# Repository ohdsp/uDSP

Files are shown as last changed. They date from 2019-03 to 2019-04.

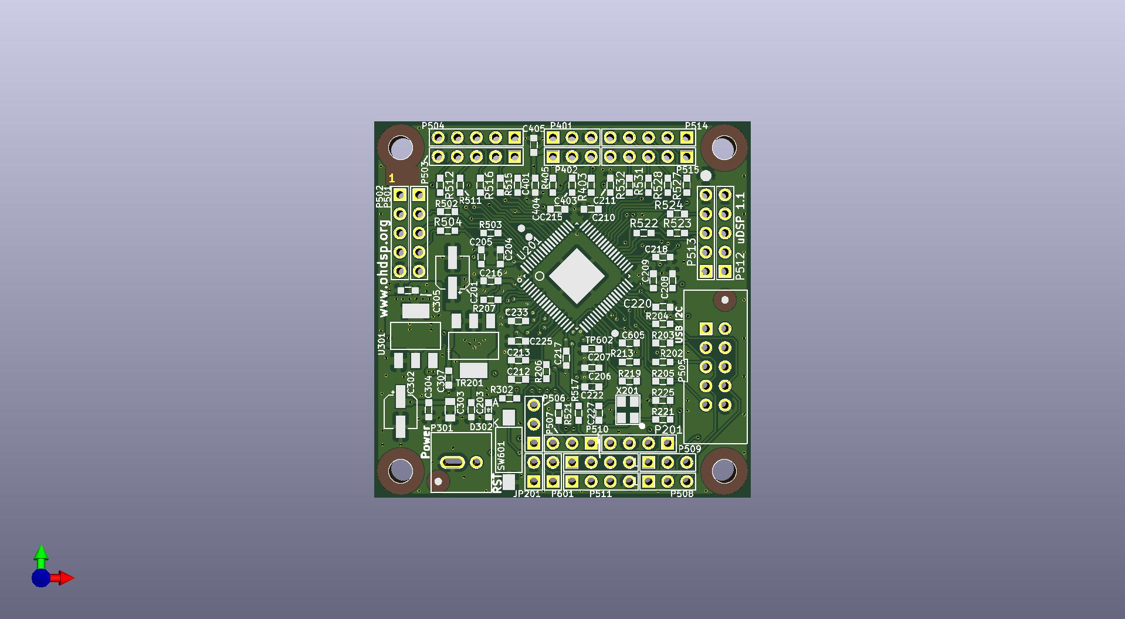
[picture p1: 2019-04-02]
JPEGs/Front.jpg

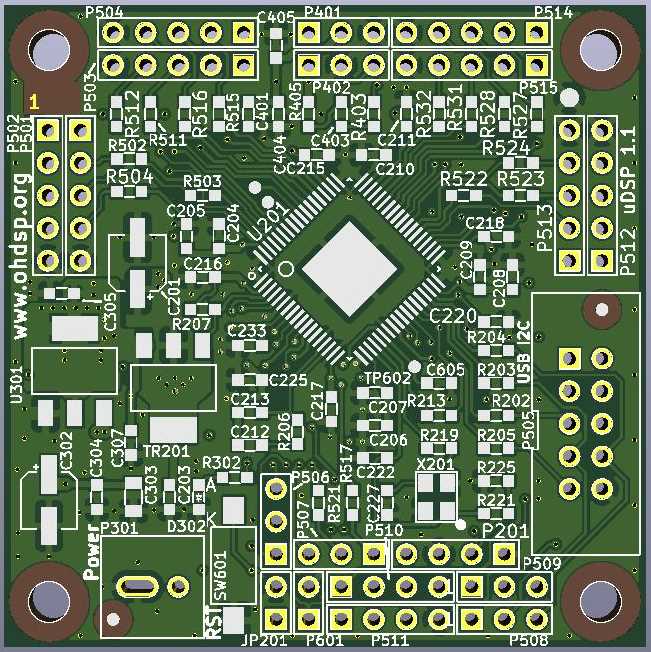
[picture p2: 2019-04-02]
JPEGs/Front - small.jpg

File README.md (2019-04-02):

# [Open Hardware DSP Platform](www.ohdsp.org)
## uDSP 1.1
### A 5cm x 5cm DSP board using Analog Device SigmaDSP devices
### Supports ADAU1466, ADAU1462, ADAU1452, ADAU1451, ADAU1450
### Selfboot and external control supported
### All I/O routed out
---
# README
### Disclaimer
Copyright Paul Janicki 2019

Licensed under the TAPR Open Hardware License (www.tapr.org/OHL)

This documentation is distributed WITHOUT ANY EXPRESS OR IMPLIED WARRANTY, INCLUDING OF MERCHANTABILITY, SATISFACTORY QUALITY AND FITNESS FOR A PARTICULAR PURPOSE.

### Changelog
1.1:
Add CS1 and CS2 to SPI header - removed 3V3 power
Add 3V3 monitor option to reset circuit

### What is this repository for?

**Quick summary**

This is a simple self-bootable DSP board with 4 I2S input and 4 I2S output connectors. When used with the ADAU146x, ADAU1451 and ADAU1452 parts there are also optical input and output connectors for off-board mounted connectors. 

There is an SPI connector for connection to the Analog Devices SigmaStudio USBi to EZ-Board Adapter (ADZS-USBI2EZB) or equivalent. 

The board also features master and slave SPI connectors for use with other boards. 

The board has space for a self-boot EEPROM. When used with the ADZS-USBI2EZB or compatible device the board can be programmed to selfboot with the last program written. The board can also be controlled using an external mircocontroller.

This board forms part the of the open hardware DSP platform which is designed to be a highly customisable and flexible DSP platform. 

This repository contains the KiCad design files, manufacturing Gerber/drill files, and PDF/drawing files for this board.

### What is the project folder structure?
Most folder names are self explanatory. Starting from the top level:
*uDSP*
+ *Bill of Materials*  - This contains the bill of materials in CVS, LibreOffice Calc and XML formats
+ *Drawings* - This contains PDF and SVG Schematic and PCB files
+ *Gerbers* - This contains the PCB Gerbers and drill drawings for manufacture, there is also a zip file ready to send to most manufacturers
+ *KiCad* - This contains the original KiCad schematic and PCB design files

### How do I get set up?

**Summary of set up**

1. Set your self up a directory on a local disk, something simple will make life easier (eg C:\Electronics on Windows as used here), but anywhere will do just fine.
2. Download the Kicad-Libs from [https://github.com/ohdsp/KiCad-Libs](https://github.com/ohdsp/KiCad-Libs) and place in C:\Electronics\Kicad-Libs (or your chosen folder) 
3. Create a OHDSP subdirectory in C:\Electronics (so C:\Electronics\OHDSP)
3. Download this project to C:\Electronics\OHDSP\uDSP
4. Fire up Kicad
5. Open the main project file C:\Electronics\OHDSP\uDSP\KiCad\uDSP.pro
7. Do as you wish with the project, just keep it under the TAPR Open Hardware License.
Note: For library issues see below.

Make sure your git setup doesn't exclude files used in the project (like .LIB files) or things may go wrong down the line.

**KiCad Library Configuration**

Note that libraries are setup using relative paths, if you follow the above instructions things should work just fine. Below is the default library setup.

To setup eeschema component libraries:
From KiCad main window go to menu Tools -> Edit Schematic Symbols. In the new Window go to menu Preferences -> Manage Symbol Libraries.

On the new "Symbol Libraries" window select the "Project Specific Libraries" tab. The "Append Library" and "Remove Library" buttons can be used to add/remove enteries.
The standard setup is:

| | Active | Nickname | Library Path | Plugin Type | Options | Description |
|---|---|---|---|---|---|---|
| 1 | Ticked | power | ${KICAD_SYMBOL_DIR}/power.lib | Legacy | (blank) | (blank) |
| 2 | Ticked | MyKiCadLibs-Lib | ${KIPRJMOD}/../../../KiCad-Libs/MyKiCadLibs-Lib.lib | Legacy | (blank) | (blank) |

${KICAD_SYMBOL_DIR}  is set under the Enviromnet Variable Configuration. Close Symbol Libraries dialogue and go "Preferences" -> "Configure Paths..."

${KICAD_SYMBOL_DIR} is set to C:\Program Files\KiCad\share\kicad\library - this is the default for a KiCad install on the C drive

${KIPRJMOD} is automatically set to the location of the project (.pro file), in this example this would be C:\Electronics\OHDSP\uDSP\KiCad

To setup Pcbnew libraries:
From KiCad main window go to menu Tools -> Edit PCB Footprints. In the new Window go to menu Preferences -> Manage Symbol Libraries.

On the new "Symbol Libraries" window select the "Project Specific Libraries" tab. The "Append Library" and "Remove Library" buttons can be used to add/remove enteries.
The standard setup is:

| | Active | Nickname | Library Path | Plugin Type | Options | Description |
|---|---|---|---|---|---|---|
| 1 | Ticked | MyKiCadLibs-Footprints | ${KIPRJMOD}/../../../KiCad-Libs/MyKiCadLibs-Footprints.pretty | KiCad | (blank) | (blank) |

${KIPRJMOD} is automatically set to the location of the project (.pro file), in this example this would be C:\Electronics\OHDSP\uDSP\KiCad

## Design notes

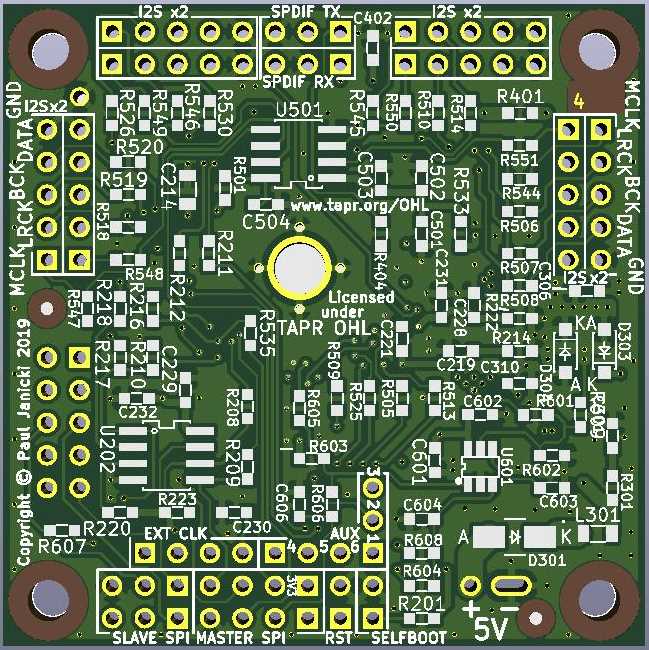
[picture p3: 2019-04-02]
JPEGs/Bottom - small.jpg

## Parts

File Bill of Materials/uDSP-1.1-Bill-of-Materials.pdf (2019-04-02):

ADC-PCM4202-SE-Bill-of-Materials-1.1

Licensed under the TAPR Open Hardware License (www.tapr.org/OHL)

### uDSP-1.1 Bill of Materials 02 April 2019

Reference | Quantity | Footprint | Value | Description | Type | Voltage | Size | Tolerance | Power | Current
C201 | 1 CAP-SMD-SIZE-B | | 22u | 'Low impedance aluminium electrolytic capacitor - Panasonic FP, FK or Similar | 'Case B SMD Aluminium Electrolytic | '6V3 | ' | ' | ' | '
C203 C204 C206 C208 C210 C215 C216 C217 C218 C225 C229 C230 C233 C304 C305 C307 C404 C405 C503 C602 C605 C606 | 22 SMD-0603 | | 100n | 'Ceramic capacitor | 'X7R | '50V | '0603 | '10% | ' | '
C205 C207 C209 C211 C220 C403 C603 C604 | 8 SMD-0603 | | 10n | 'Ceramic capacitor | 'X7R | '50V | '0603 | '10% | ' | '
C212 | 1 SMD-0603 | | 5n6 | 'Ceramic capacitor | 'X7R | '50V | '0603 | '10% | ' | '
C213 | 1 SMD-0603 | | 150p | 'Ceramic capacitor | 'C0G | '50V | '0603 | '5% | ' | '
C214 | 1 SMD-0805 | | 10u | 'Ceramic capacitor | 'X5R | '10V | '0805 | '20% | ' | '
C219 C228 C301 C401 C501 | 5 SMD-0603 | | 100p | 'Ceramic capacitor | 'NP0 | '50V | '0603 | '5% | ' | '
C221 C231 C232 | 3 SMD-0603 | | 10u | 'Ceramic capacitor | 'X5R | '10V | '0603 | '10% | ' | '
C222 C227 | 2 SMD-0603 | | 33p | 'Ceramic capacitor | 'C0G | '25V | '0603 | '5% | ' | '
C302 | 1 CAP-SMD-SIZE-B | | 10u | 'Low impedance aluminium electrolytic capacitor - Panasonic FP, FK or Similar | 'Case B SMD Aluminium Electrolytic | '10V | ' | ' | ' | '
C303 | 1 SMD-0805 | | 22u | 'Ceramic capacitor | 'X5R | '25V | '0805 | '20% | ' | '
C306 | 1 SMD-0603 | | 22u | 'Ceramic capacitor | 'X5R | '10V | '0603 | '20% | ' | '
C310 C601 | 2 SMD-0603 | | 10u | 'Ceramic capacitor | 'X5R | '10V | '0603 | '20% | ' | '
C402 C502 | 2 SMD-0603 | | 22u | 'Ceramic capacitor | 'X5R | '10V | '0603 | '10% | ' | '
C504 | 1 SMD-0603 | | 1n | 'Ceramic capacitor | 'X7R | '50V | '0603 | '10% | ' | '
D301 | 1 DIODE-SMA | | B240A | 'B240A 2A 40V Schottky Rectifier - SMA (DO-214AC) | ' | ' | ' | ' | ' | '
D302 | 1 SMD-0603-LED | | LED 0603 | 'LED - SMD - Vf 1.8V to 2.2V | ' | ' | '0603 | ' | ' | '
D303 D304 | 2 DIODE-SOD-123 | | 1N5819HW | '1A 40V Schottky Rectifier - SOD-123 | ' | ' | ' | ' | ' | '
JP201 P601 | 2 CONN_SIL_2_1MM | | CONN_2x1 | '1x2 2.54mm pitch pin header | ' | ' | ' | ' | ' | '
L301 | 1 SMD-0805 | | 600R@100MHz | 'Ferrite bead, current rating 1A or higher, 600R@100MHz | ' | ' | '0805 | ' | ' | '=>2A
P201 P510 P511 | 3 CONN_SIL_4_1MM | | CONN_4x1 | '1x4 2.54mm pitch pin header | ' | ' | ' | ' | ' | '
P301 | 1 CONN-2WAY-2.54mm-3.81mm-SPACING | | CONN_2x1 | '2 way screw terminal, any 2.54mm to 3.81mm pitch part | ' | ' | ' | ' | ' | '
P401 P402 P506 P507 P508 P509 | 6 CONN_SIL_3_1MM | | CONN_3x1 | '1x3 2.54mm pitch pin header | ' | ' | ' | ' | ' | '
P505 | 1 CONN_DIL_2X5_BOX_1MM | | CONN_02X05 | '2x5 2.54mm pitch box header | ' | ' | ' | ' | ' | '
P501 P502 P503 P504 P512 P513 P514 P515 | 8 CONN_SIL_5_1MM | | CONN_5x1 | '1x5 2.54mm pitch pin header | ' | ' | ' | ' | ' | '
R202 R208 R209 R210 R211 R212 R213 R216 R403 R404 R518 R519 R520 R522 R523 R524 R526 R527 R528 R530 R531 R532 R544 R545 R546 R547 R548 R549 R550 R551 | 30 SMD-0603 | | 22 | 'Thick or thin film resistor | ' | ' | '0603 | '1% | '63mW | '
R203 R204 R205 R502 R503 R504 R506 R507 R508 R510 R511 R512 R514 R515 R516 R535 R607 | 17 SMD-0603 | | 0 | 'Thick or thin film resistor | ' | ' | '0603 | '1% | '63mW | '
R206 | 1 SMD-0603 | | 4k3 | 'Thick or thin film resistor | ' | ' | '0603 | '1% | '63mW | '
R201 R207 R501 | 3 SMD-0603 | | 1K | 'Thick or thin film resistor | ' | ' | '0603 | '1% | '63mW | '
R214 R222 R401 R533 | 4 SMD-0603 | | 1 | 'Thick or thin film resistor | ' | ' | '0603 | '1% | '63mW | '
R217 R220 R223 R405 R602 | 5 SMD-0603 | | 10K | 'Thick or thin film resistor | ' | ' | '0603 | '1% | '63mW | '
R219 R604 R605 R606 | 4 SMD-0603 | | 100 | 'Thick or thin film resistor | ' | ' | '0603 | '1% | '63mW | '
R218 R221 R225 R609 | 4 SMD-0603 | | N/F | 'Thick or thin film resistor | ' | ' | '0603 | '1% | '63mW | '
R301 | 1 SMD-0603 | | 47 | 'Thick or thin film resistor | ' | ' | '0603 | '1% | '63mW | '
R302 | 1 SMD-0603 | | 470 | 'Thick or thin film resistor | ' | ' | '0603 | '1% | '63mW | '
R505 R509 R513 R517 R521 R525 | 6 SMD-0603 | | 4K7 | 'Thick or thin film resistor | ' | ' | '0603 | '1% | '63mW | '
R601 | 1 SMD-0603 | | 18K7 | 'Thick or thin film resistor | ' | ' | '0603 | '1% | '63mW | '
R603 R608 | 2 SMD-0603 | | 2K2 | 'Thick or thin film resistor | ' | ' | '0603 | '1% | '63mW | '
SW601 | 1 SW_TACT_SMD_FSMSM | | FSMSM | '3.5mm x 6mm SMD tactile switch - e.g. Alcoswitch FSMSM | ' | ' | ' | ' | ' | '
TR201 | 1 IC-SOT-223 | | NJT4030PT3G | 'On Semi NJT4030PT3G PNP Transistor (min 2W, 200hFE, 2A) | ' | ' | ' | ' | ' | '
U201 | 1 IC-LFCSP72-HANDFIT | | ADAU1452WBCPZ | 'SigmaDSP Digital Audio Processor - Use ADAU1462, ADAU1466, ADAU1452, ADAU1451, or ADAU1450 | ' | ' | ' | ' | ' | '
U202 | 1 IC_SOIC_8 | | M95M01-RMN6TP | '1 Mbit SPI Bus Serial EEPROM - 8 pin SOIC | ' | ' | ' | ' | ' | '
U301 | 1 IC-SOT-223 | | TLV1117LV33DCY | 'TLV1117LV 1-A, Positive Fixed-Voltage, Low-Dropout Regulator - Fixed 3V3 | ' | ' | ' | ' | ' | '
U501 | 1 IC_SOIC_8 | | NB3L553 | 'On Semi - 1:4 Clock Fanout Buffer | ' | ' | ' | ' | ' | '
U601 | 1 IC-SOT23-6 | | NCP308SNADJT1G | 'On Semi NCP308SNADJT1G SOT-23-6 TSOP-6 Supervisor | ' | ' | ' | ' | ' | '
X201 | 1 XTAL_3.2x2.5_4PIN | | 24M576 | 'Crystal 3.2mm x 2.5mm - eg Abracon ASE-24.576MHZ-LC-T | ' | ' | ' | ' | ' | '

### Open Hardware DSP Platform – www.ohdsp.org

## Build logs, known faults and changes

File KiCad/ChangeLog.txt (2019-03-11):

Schematic changelog revision 2.0:
Changes jumpers from CN to JP designators (JP201,JP401)
Change various 22uF to 10uF
Removed R from all resistors values
Change R234,R235 from 68ohm to 75ohm
Replace NB3L553 supply inductors L501/L502 with resistors R584/R585 (still 0805 parts)
General tidy up of schematics, part numbers, text etc.
Change P304 from 5mm/5.08mm to smaller connector (same as other boards)
Change D301,D302 to B240A
Change D303,D305,D306,D307,D501-D512 to SS14
Update connectors with 1mm holes
Change PVDD filter resistor to inductor (L202)
Change L302 to TYS50404R7N-10
Change mounting holes and added fiducials
Delete C259, C262, C255, C330,C332
Change U302 to lower cost TLV1117LV33DCY fixed output regulator
Added new SPI slave and master connector P511/P512
Moved/added R227, R236, R248, R586 and R587
Change C216 to 10uF
Removed C202-C204
Updated all parts with extra details/fields
Change clock buffer pin orders

PCB changelog revision 2.0:
Added Master and Slave SPI connectors P511 and P512
Moved EEPROM/SPI/I2C connectors
Changed L501/L502 to R584/R585
Silkscreen changes
Renamed jumpers from CN to JP designators
Fixed disconnected ground stitching vias
Change D301 from SMB to SMA footprint
Update all 2x5 header footprints with key
Update all headers with 1mm holes
Change PVDD 1R resistor to inductor (L202)
Chage L302 to TYS50404R7N-10
Change mounting holes
Delete C259, C262, C255, C330,C332
Update ADP2301 footprint with pin 1 indicator
Change U302 to 1117 regulator
Update design rules
Added fiducials
Change U302 to SOT223
Moved/added R227, R236, R248, R586 and R587
Moved reset switch, crystals and associatedparts
Increase part spacing around U202
Removed C202-C204
Moved U502, U203, and surrounding parts
Adjusted capacitor spacing around ADAU1452/U201
Change clock buffer pin orders/relayout buffers

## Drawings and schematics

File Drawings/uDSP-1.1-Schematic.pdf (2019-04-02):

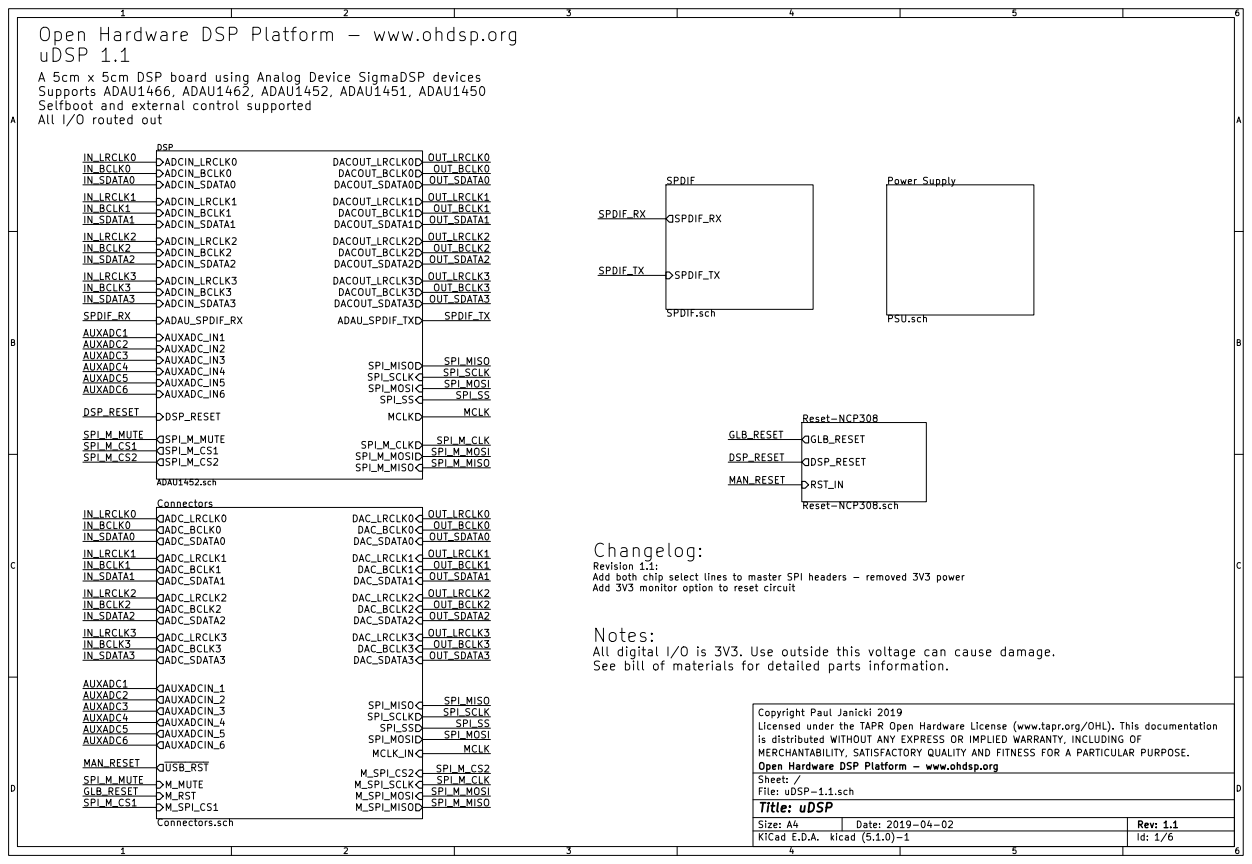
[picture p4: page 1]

Open Hardware DSP Platform - www.ohdsp.org
uDSP 1.1
A 5cm x 5cm DSP board using Analog Device SigmaDSP devices
Supports ADAU1466, ADAU1462, ADAU1452, ADAU1451, ADAU1450
Selfboot and external control supported
All I/O routed out

IN_BCLK0
IN_SDATA0 | OUT_SDATA0

IN_BCLK1 | OUT_BCLK1
IN_SDATA1 | OUT_SDATA1

IN_BCLK2 | OUT_BCLK2
IN_SDATA2 | OUT_SDATA2

IN_BCLK3 | OUT_BCLK3
IN_SDATA3 | OUT_SDATA3

GLB_RESET RST_IN

SPI_M_MOSI
SPI_M_MISO

IN_SDATA0

Changelog: Revision 1.1: Add both chip select lines to master SPI headers - removed 3V3 power

IN_BCLK1

OUT_LRCLK1

Add 3V3 monitor option to reset circuit

IN_BCLK2
IN_SDATA2

Notes:
All digital I/O is 3V3. Use outside this voltage can cause damage.
See bill of materials for detailed parts information.

IN_BCLK3
IN_SDATA3

AUXADCIN_1 AUXADCIN_2 AUXADCIN_3 AUXADCIN_4 AUXADCIN_5 AUXADCIN_6

Copyright Paul Janicki 2019
Licensed under the TAPR Open Hardware License (www.tapr.org/OHL). This documentation
is distributed WITHOUT ANY EXPRESS OR IMPLIED WARRANTY, INCLUDING OF
MERCHANTABILITY, SATISFACTORY QUALITY AND FITNESS FOR A PARTICULAR PURPOSE.
File: uDSP-1.1.sch Sheet: / Open Hardware DSP Platform - www.ohdsp.org

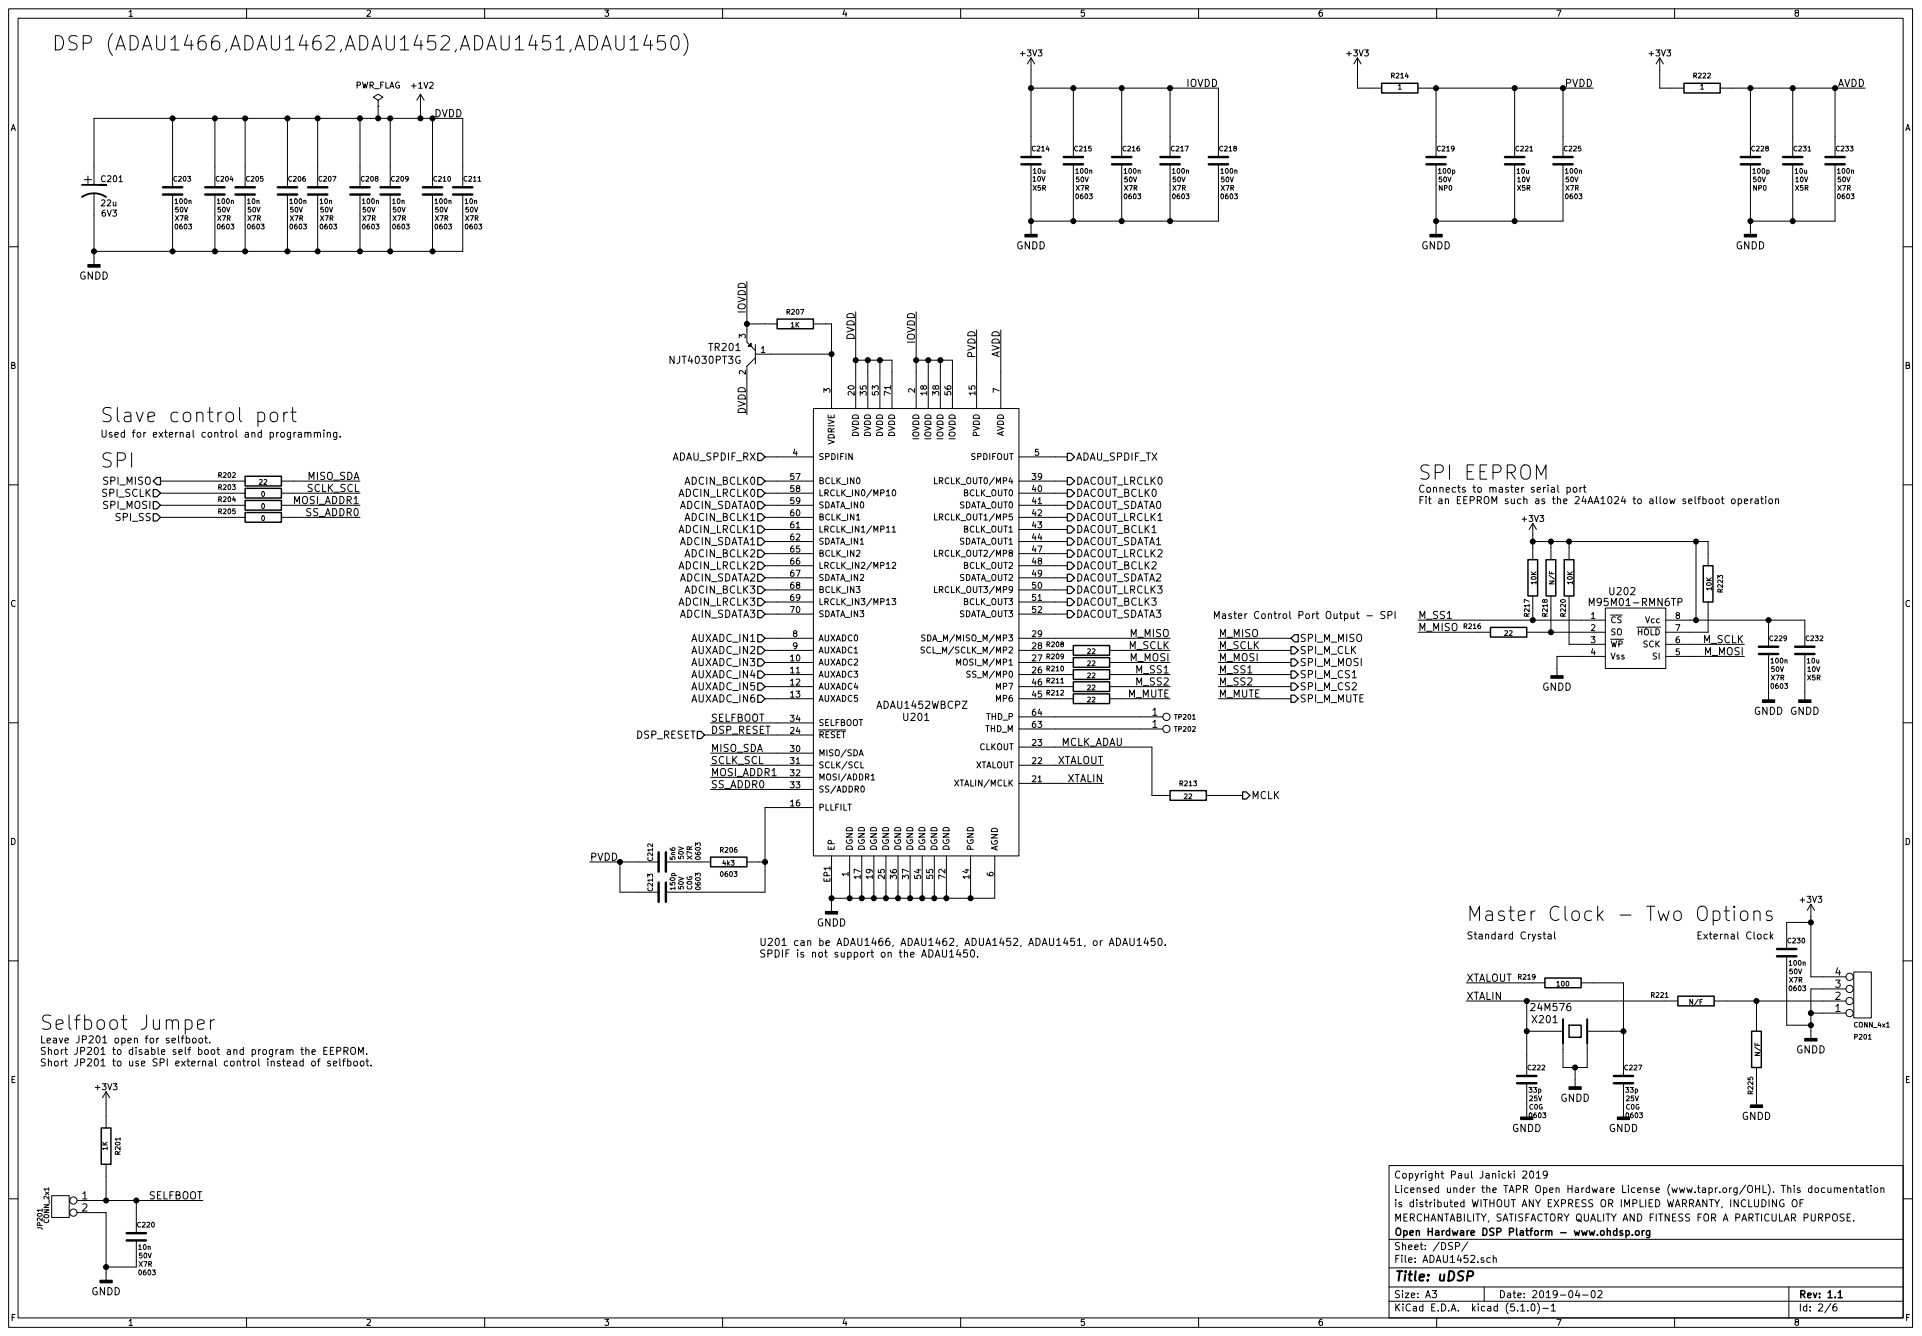
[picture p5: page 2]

1 AUXADC2 10 AUXADC3 11 AUXADC4 12 AUXADC5 13 PGND 14 PVDD 15 PLLFILT 16 DGND 17 IOVDD 18 DGND 19 IOVDD

2 DVDD 20 XTALIN/MCLK 21 XTALOUT 22 CLKOUT 23 RESET 24 DGND 25 SS_M/MP0 26 MOSI_M/MP1 27 SCL_M/SCLK_M/MP2 28 SDA_M/MISO_M/MP3 29 VDRIVE

3 MISO/SDA 30 SCLK/SCL 31 MOSI/ADDR1 32 SS/ADDR0 33 SELFBOOT 34 DVDD 35 DGND 36 DGND 37 IOVDD 38 LRCLK_OUT0/MP4 39 SPDIFIN 4 BCLK_OUT0 40 SDATA_OUT0 41

Used for external control and programming.

SPI EEPROM
Connects to master serial port
Fit an EEPROM such as the 24AA1024 to allow selfboot operation

Master Clock - Two Options

SPDIF is not support on the ADAU1450.

Leave JP201 open for selfboot.

Copyright Paul Janicki 2019
Licensed under the TAPR Open Hardware License (www.tapr.org/OHL). This documentation
is distributed WITHOUT ANY EXPRESS OR IMPLIED WARRANTY, INCLUDING OF
MERCHANTABILITY, SATISFACTORY QUALITY AND FITNESS FOR A PARTICULAR PURPOSE.
File: ADAU1452.sch Sheet: /DSP/ Open Hardware DSP Platform - www.ohdsp.org

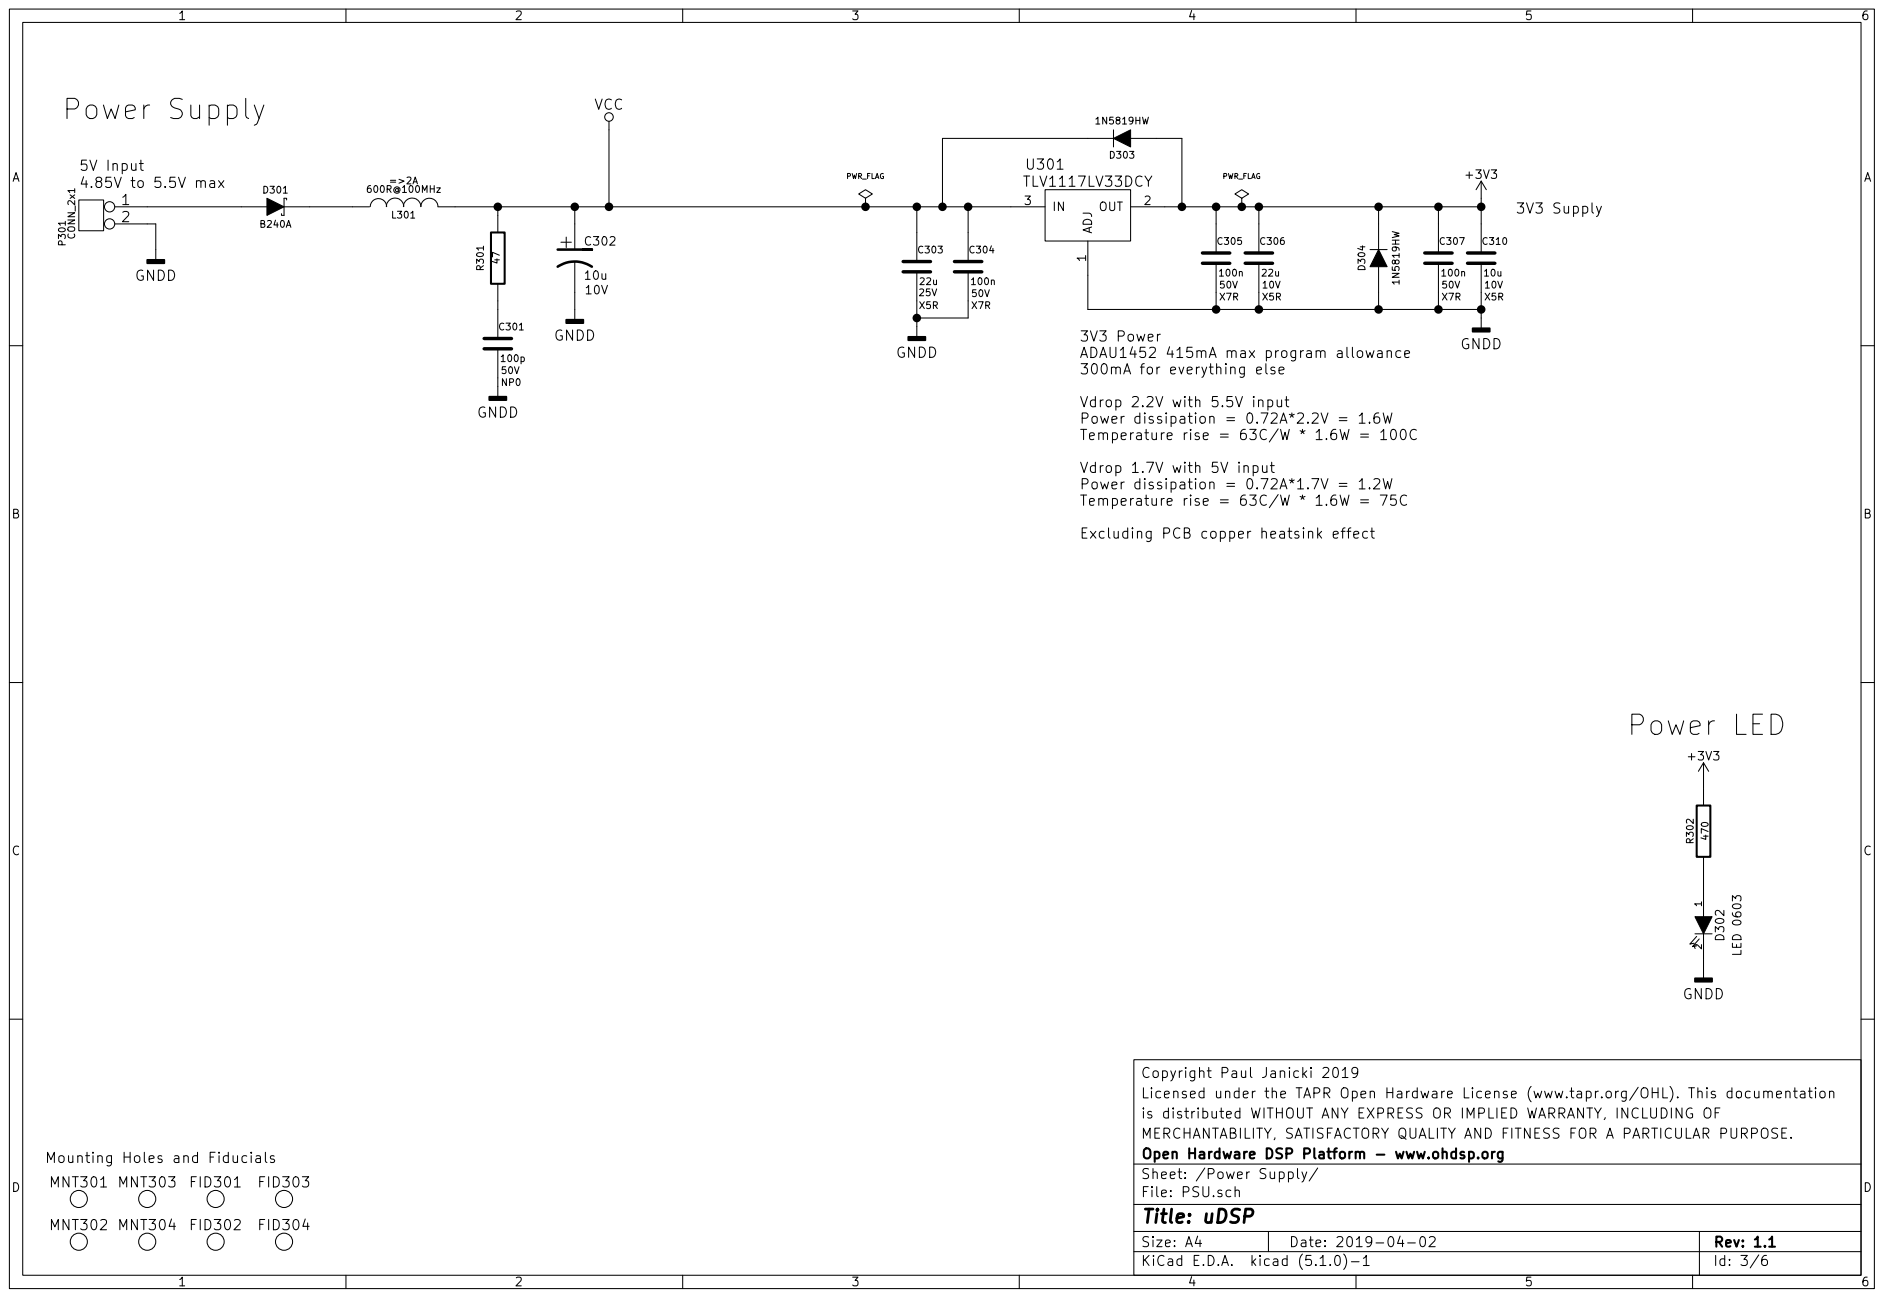
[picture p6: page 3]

5V Input
Excluding PCB copper heatsink effect 4.85V to 5.5V max

+3V3 3V3 Power ADAU1452 415mA max program allowance

Copyright Paul Janicki 2019
Licensed under the TAPR Open Hardware License (www.tapr.org/OHL). This documentation
is distributed WITHOUT ANY EXPRESS OR IMPLIED WARRANTY, INCLUDING OF
MERCHANTABILITY, SATISFACTORY QUALITY AND FITNESS FOR A PARTICULAR PURPOSE.
Open Hardware DSP Platform - www.ohdsp.org
File: PSU.sch Sheet: /Power Supply/
Id: 3/6 Title: uDSP

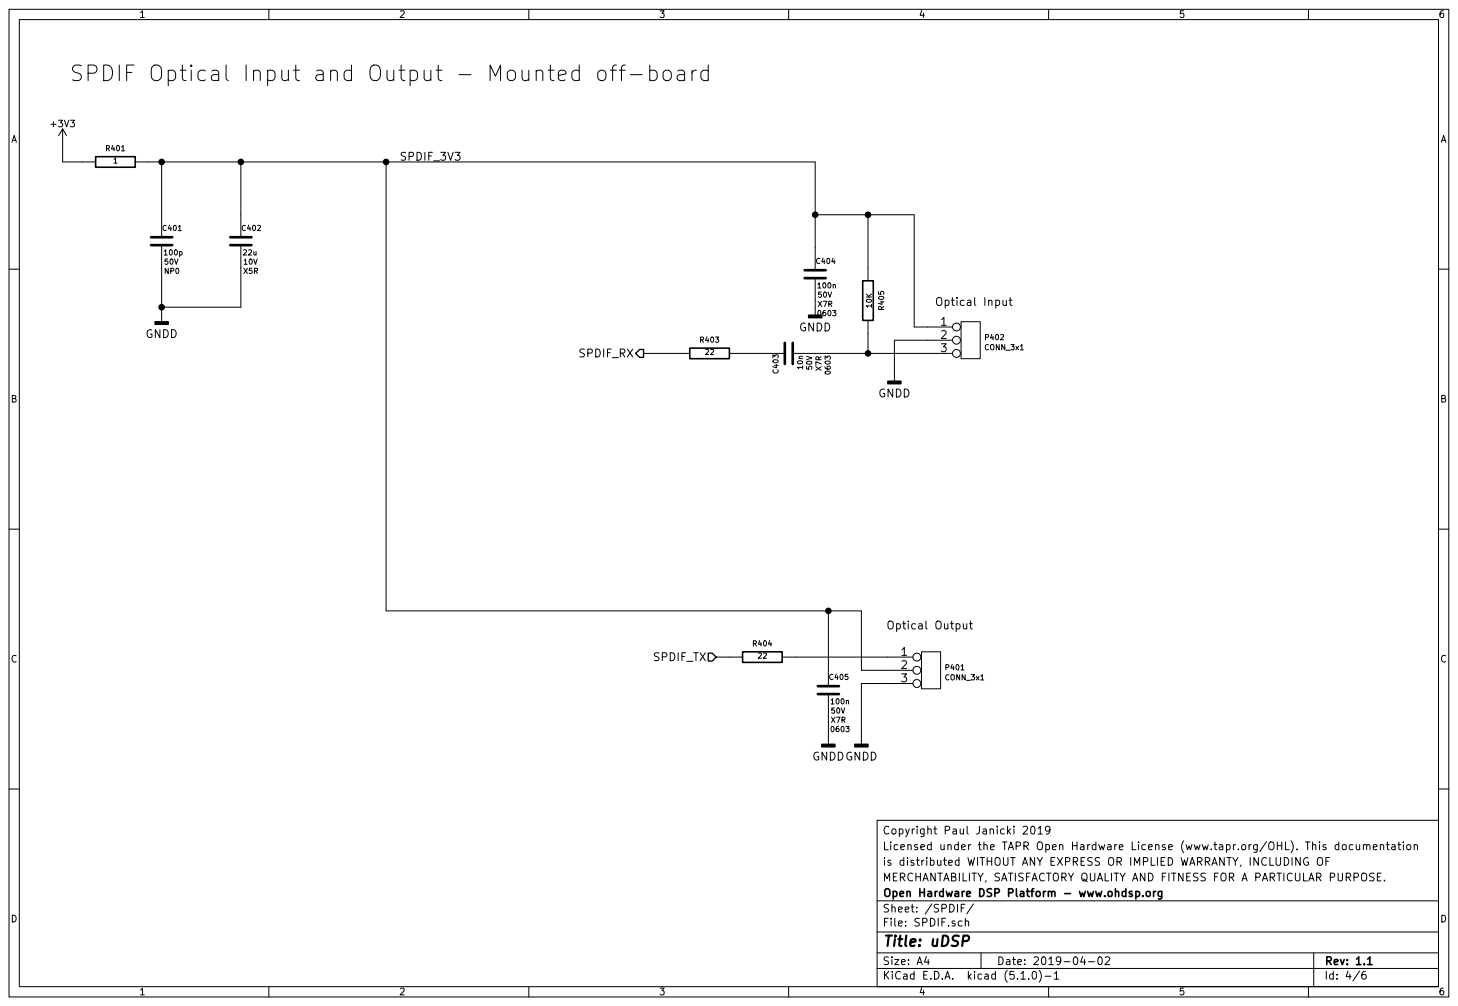
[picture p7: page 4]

SPDIF Optical Input and Output - Mounted off-board

Copyright Paul Janicki 2019
Licensed under the TAPR Open Hardware License (www.tapr.org/OHL). This documentation
is distributed WITHOUT ANY EXPRESS OR IMPLIED WARRANTY, INCLUDING OF
MERCHANTABILITY, SATISFACTORY QUALITY AND FITNESS FOR A PARTICULAR PURPOSE.
File: SPDIF.sch Sheet: /SPDIF/ Open Hardware DSP Platform - www.ohdsp.org

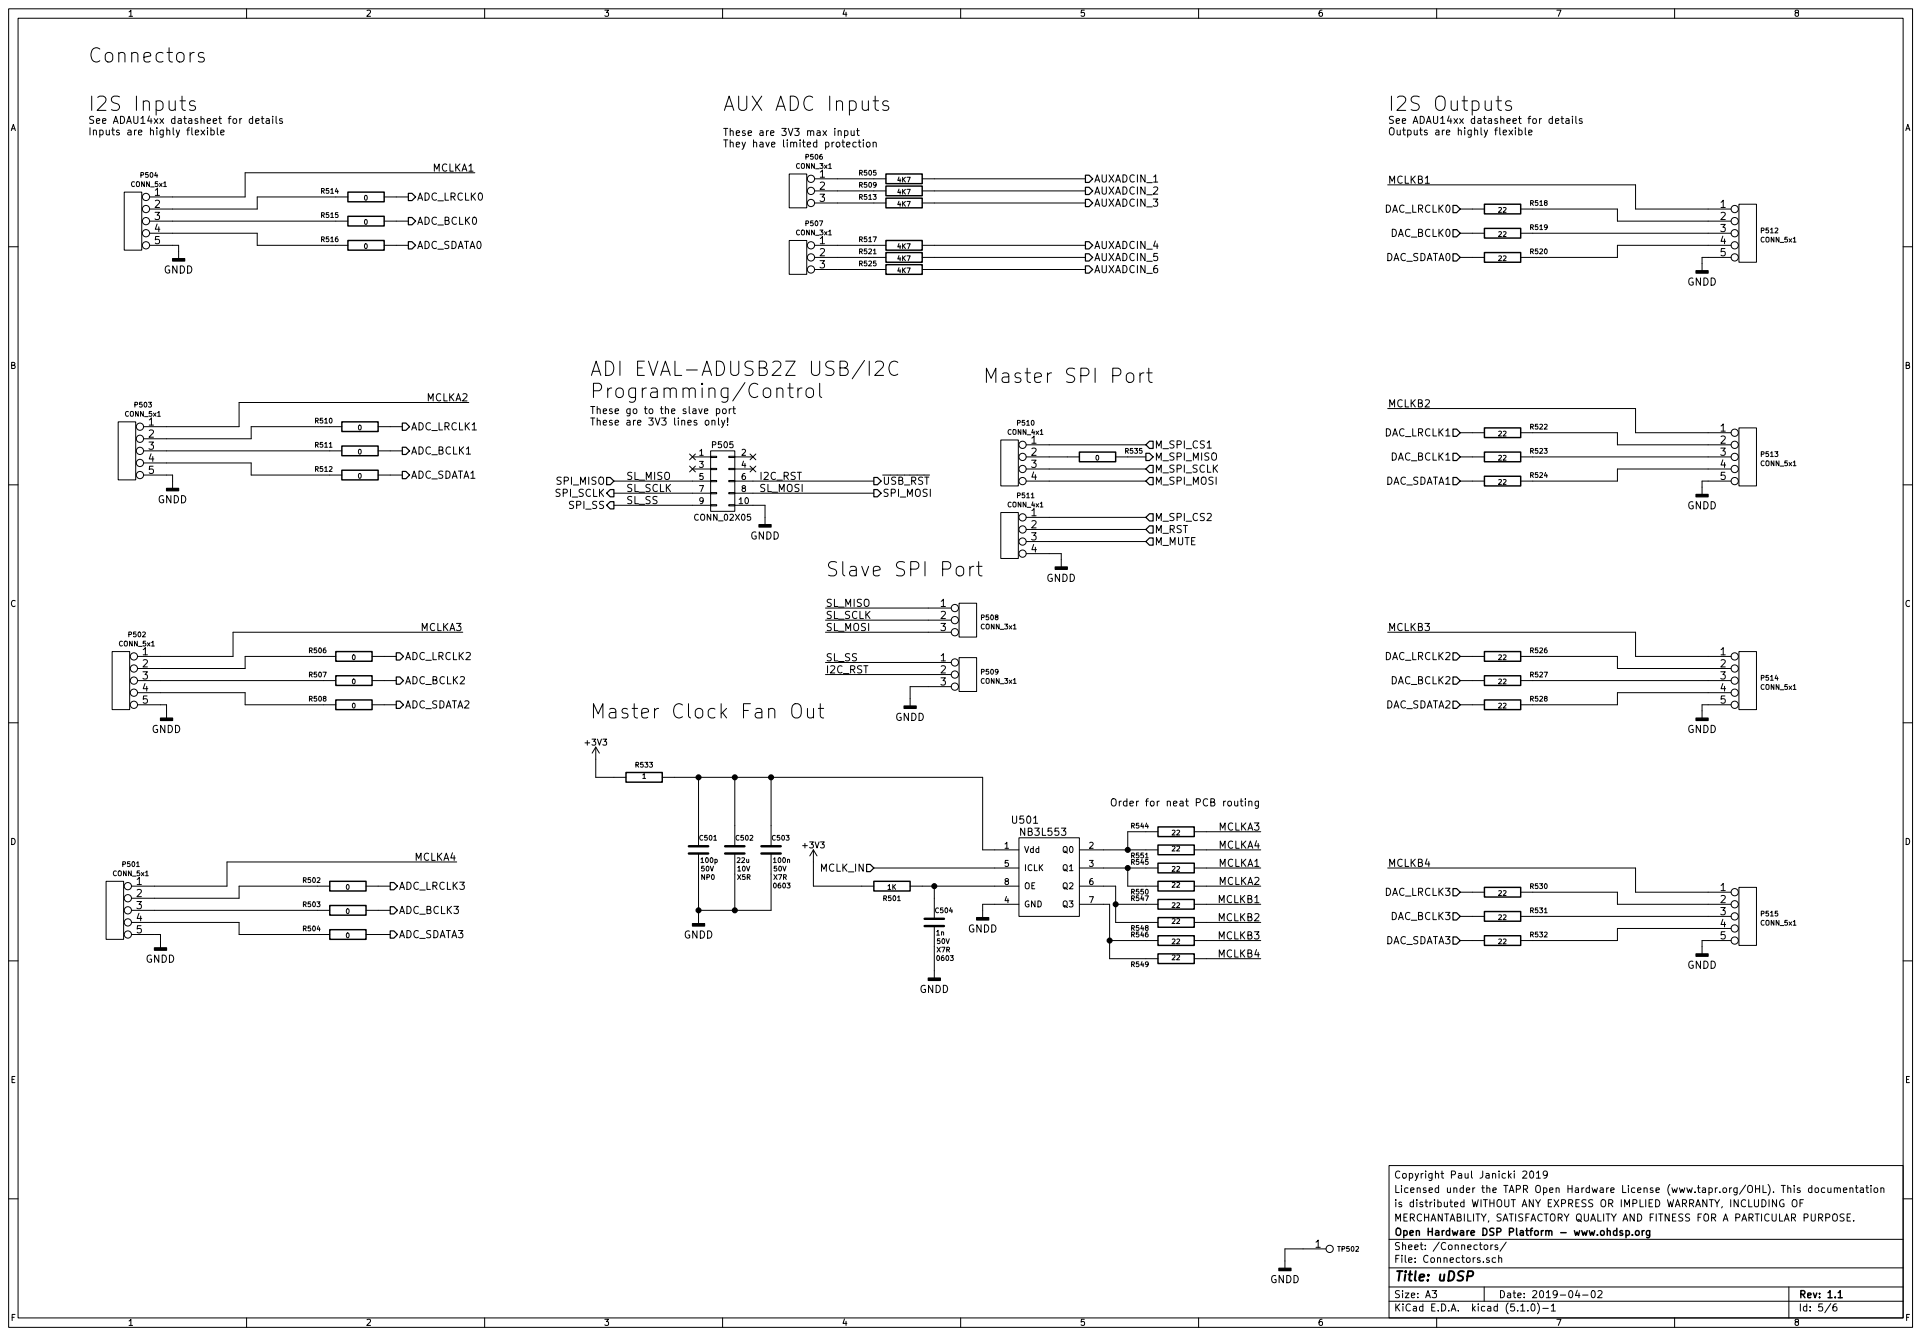
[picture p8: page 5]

I2S Outputs
See ADAU14xx datasheet for details Outputs are highly flexible

These are 3V3 max input
They have limited protection

These go to the slave port

These are 3V3 lines only! ADC_LRCLK1

Master Clock Fan Out

Order for neat PCB routing

Copyright Paul Janicki 2019
Licensed under the TAPR Open Hardware License (www.tapr.org/OHL). This documentation
is distributed WITHOUT ANY EXPRESS OR IMPLIED WARRANTY, INCLUDING OF
MERCHANTABILITY, SATISFACTORY QUALITY AND FITNESS FOR A PARTICULAR PURPOSE.
File: Connectors.sch Sheet: /Connectors/ Open Hardware DSP Platform - www.ohdsp.org

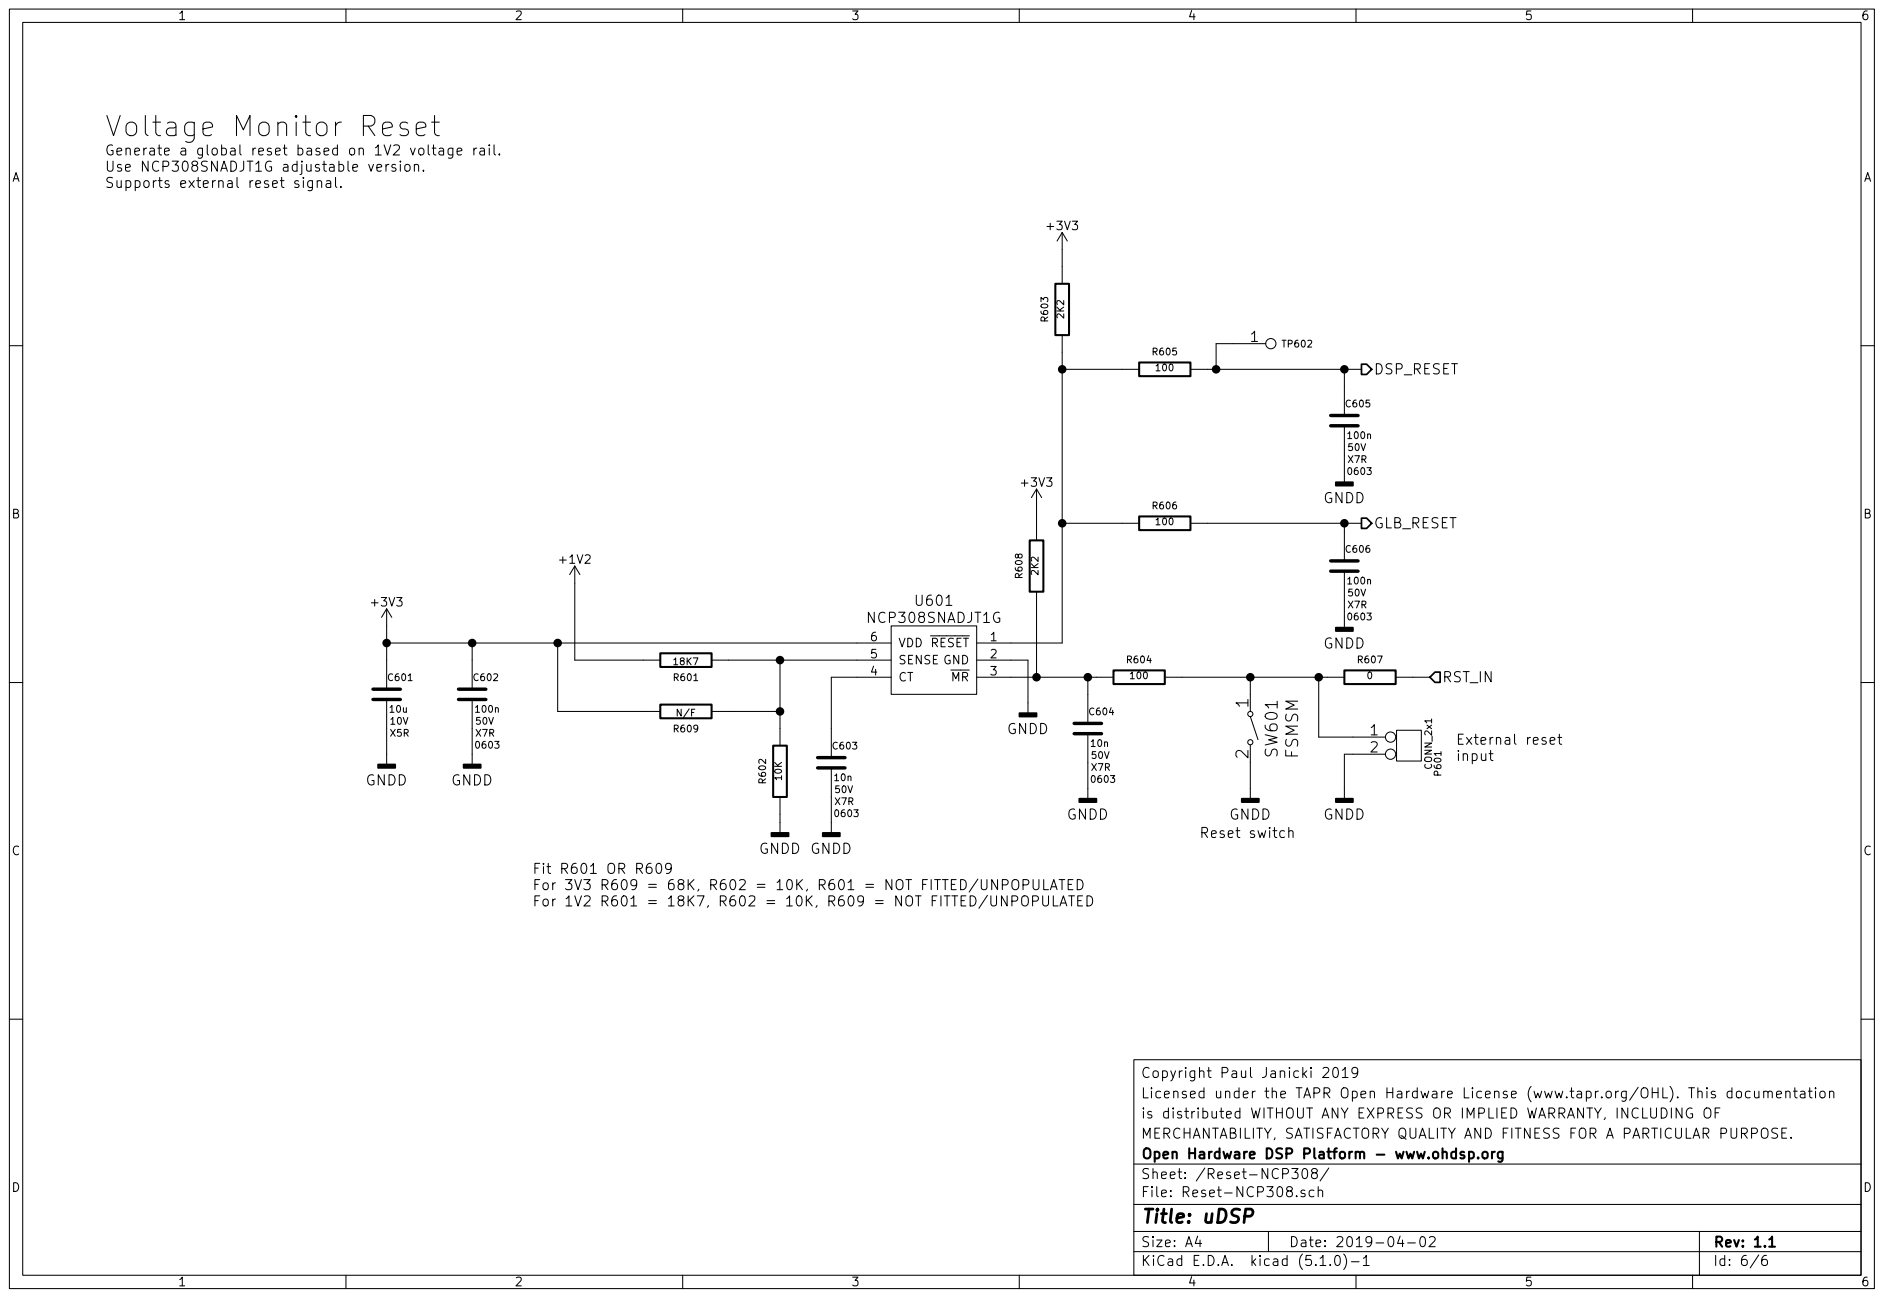
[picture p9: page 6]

Generate a global reset based on 1V2 voltage rail.
Use NCP308SNADJT1G adjustable version.
Supports external reset signal.

For 1V2 R601 = 18K7, R602 = 10K, R609 = NOT FITTED/UNPOPULATED

Copyright Paul Janicki 2019
Licensed under the TAPR Open Hardware License (www.tapr.org/OHL). This documentation
is distributed WITHOUT ANY EXPRESS OR IMPLIED WARRANTY, INCLUDING OF
MERCHANTABILITY, SATISFACTORY QUALITY AND FITNESS FOR A PARTICULAR PURPOSE.
File: Reset-NCP308.sch Sheet: /Reset-NCP308/ Open Hardware DSP Platform - www.ohdsp.org

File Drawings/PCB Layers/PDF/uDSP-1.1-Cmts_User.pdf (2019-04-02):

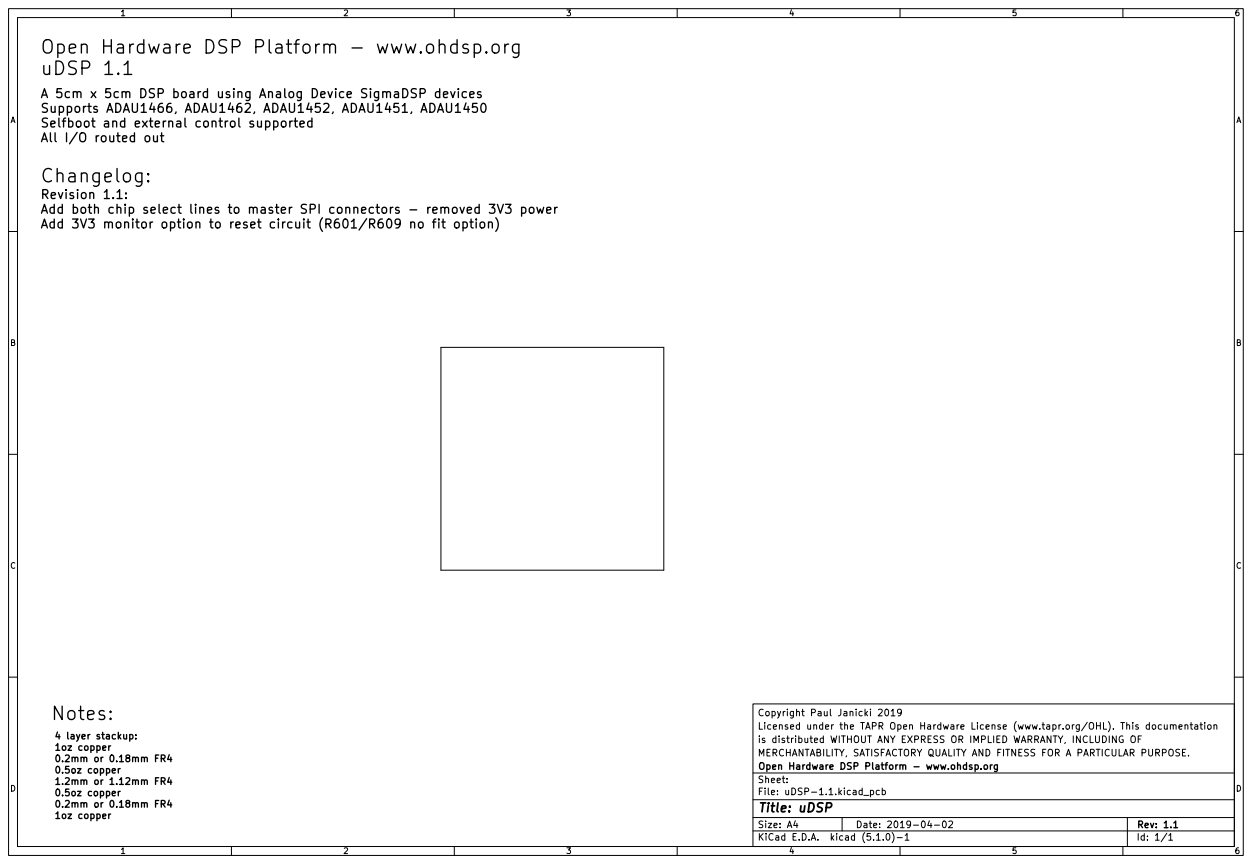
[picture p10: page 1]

Open Hardware DSP Platform - www.ohdsp.org
uDSP 1.1

A 5cm x 5cm DSP board using Analog Device SigmaDSP devices
Supports ADAU1466, ADAU1462, ADAU1452, ADAU1451, ADAU1450
Selfboot and external control supported
All I/O routed out
Changelog:
Revision 1.1:
Add both chip select lines to master SPI connectors - removed 3V3 power
Add 3V3 monitor option to reset circuit (R601/R609 no fit option)

Copyright Paul Janicki 2019
Licensed under the TAPR Open Hardware License (www.tapr.org/OHL). This documentation
is distributed WITHOUT ANY EXPRESS OR IMPLIED WARRANTY, INCLUDING OF
MERCHANTABILITY, SATISFACTORY QUALITY AND FITNESS FOR A PARTICULAR PURPOSE.
File: uDSP-1.1.kicad_pcb Sheet: Open Hardware DSP Platform - www.ohdsp.org

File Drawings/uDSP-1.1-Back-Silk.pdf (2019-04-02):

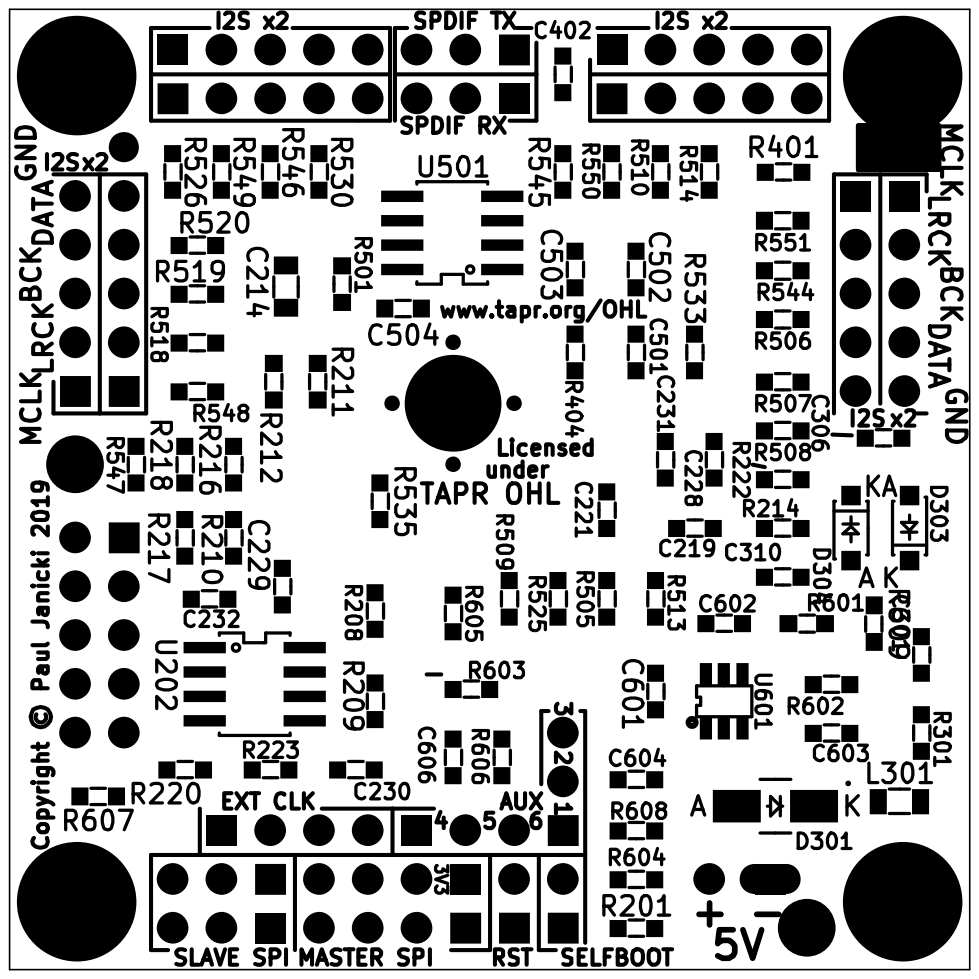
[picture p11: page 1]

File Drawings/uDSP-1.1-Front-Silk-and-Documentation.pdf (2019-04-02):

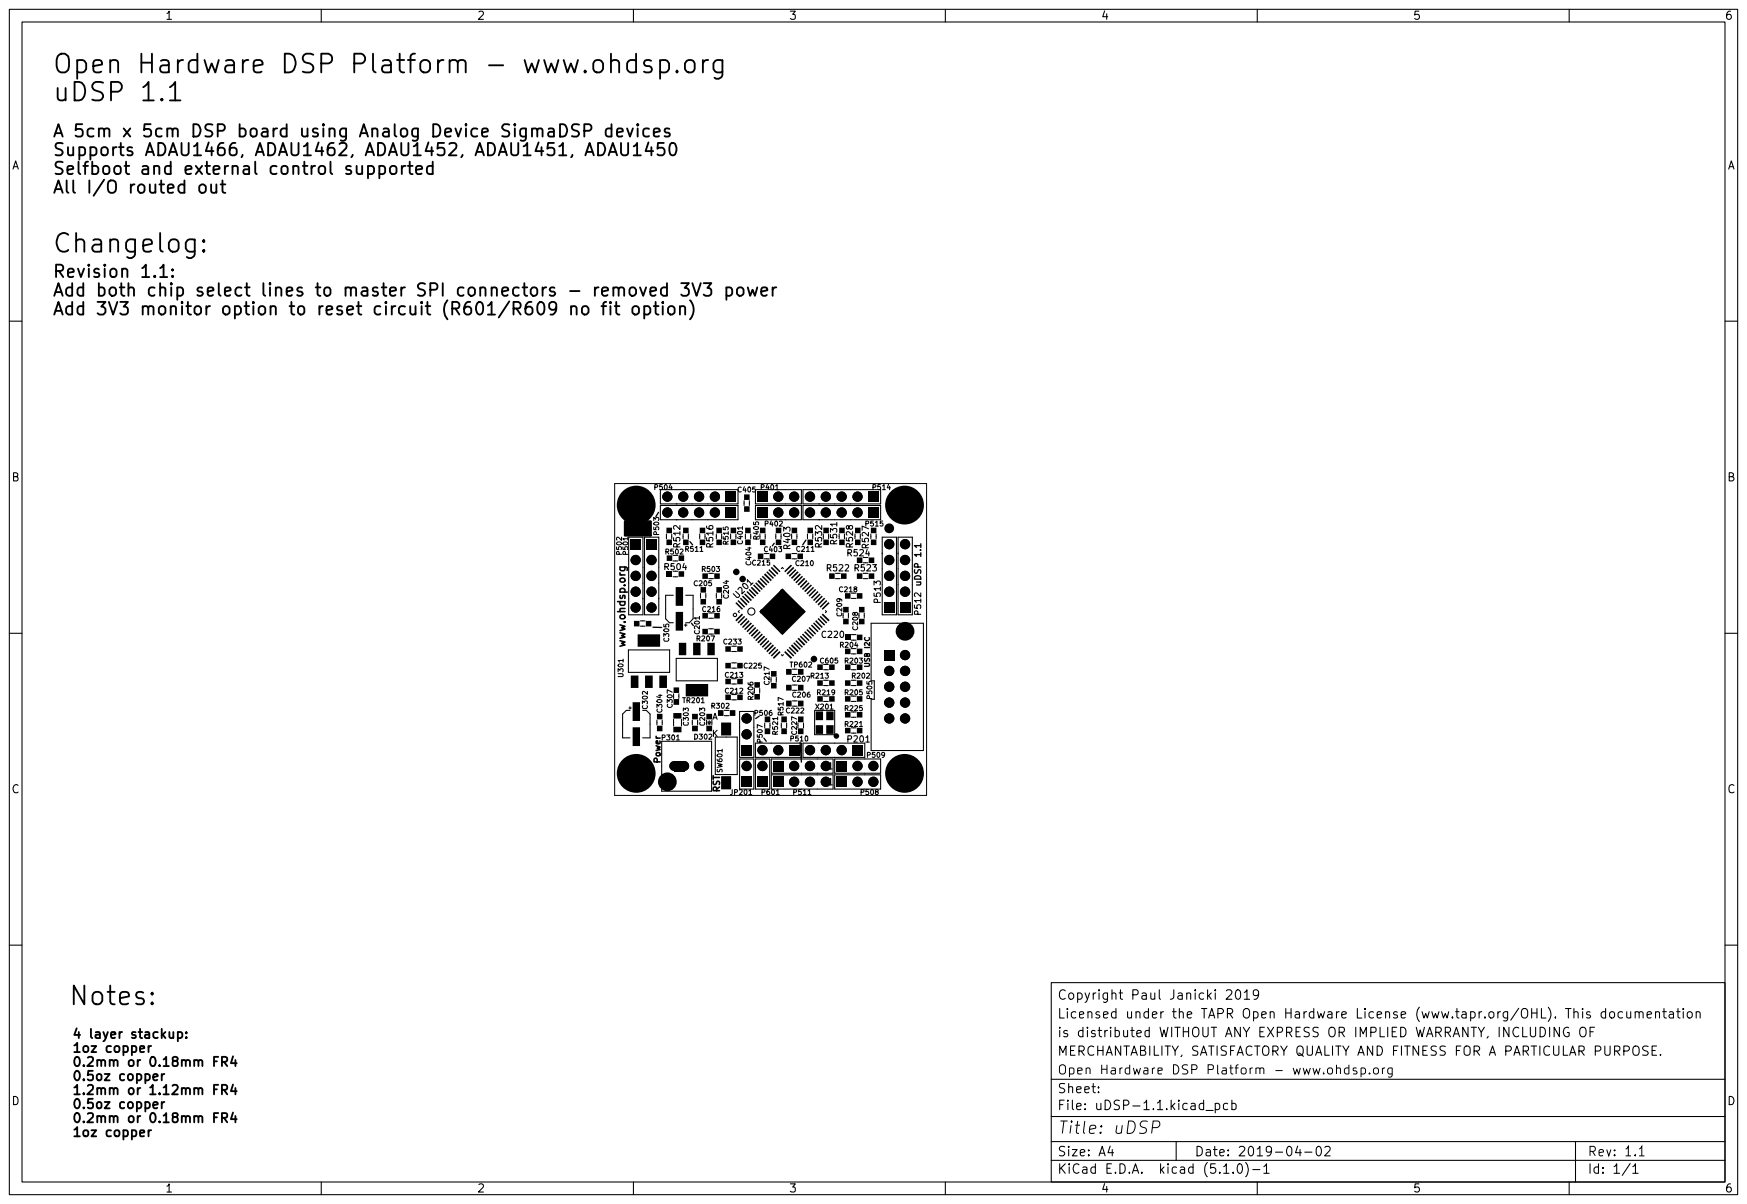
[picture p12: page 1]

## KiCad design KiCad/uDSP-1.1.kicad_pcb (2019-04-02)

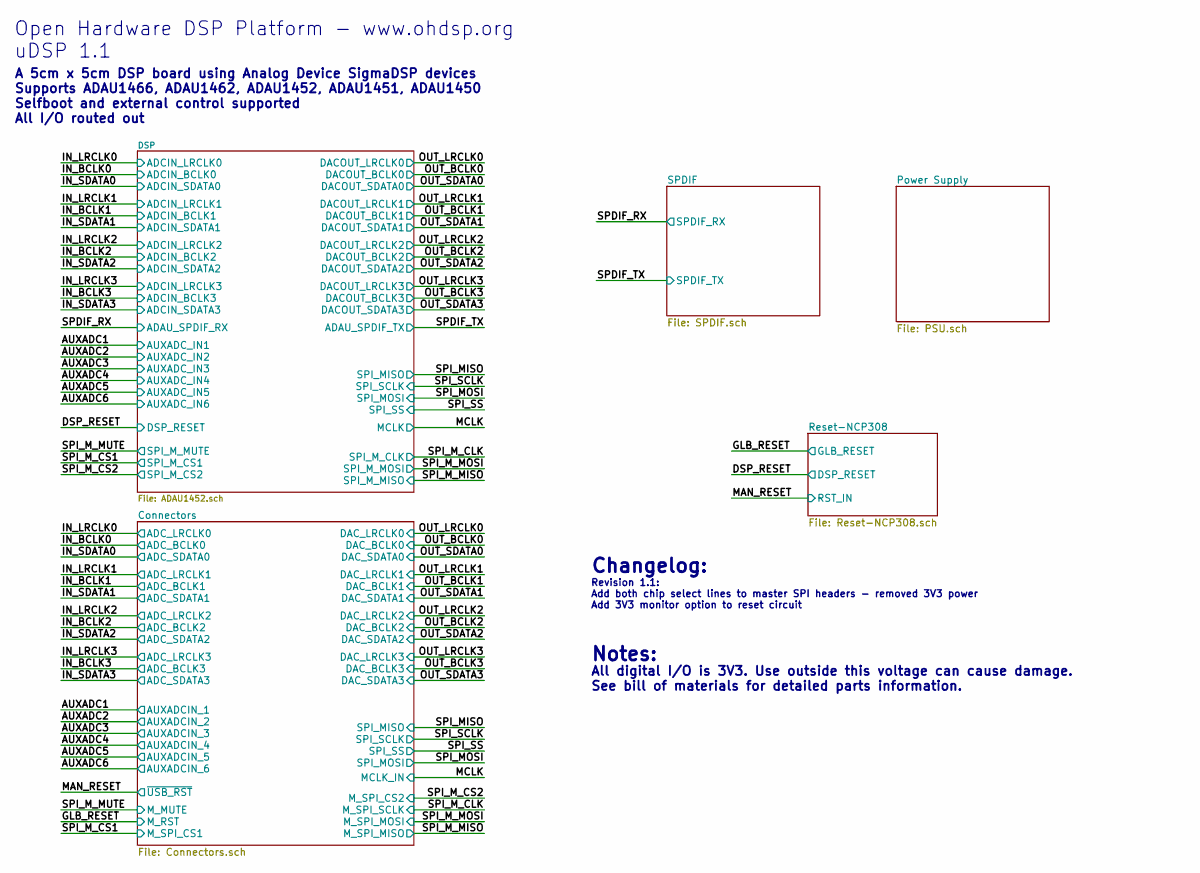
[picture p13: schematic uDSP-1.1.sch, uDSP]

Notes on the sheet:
All digital I/O is 3V3. Use outside this voltage can cause damage. See bill of materials for detailed parts information.
Notes:
A 5cm x 5cm DSP board using Analog Device SigmaDSP devices Supports ADAU1466, ADAU1462, ADAU1452, ADAU1451, ADAU1450 Selfboot and external control supported All I/O routed out
Open Hardware DSP Platform - www.ohdsp.org uDSP 1.1
Changelog:
Revision 1.1: Add both chip select lines to master SPI headers - removed 3V3 power Add 3V3 monitor option to reset circuit

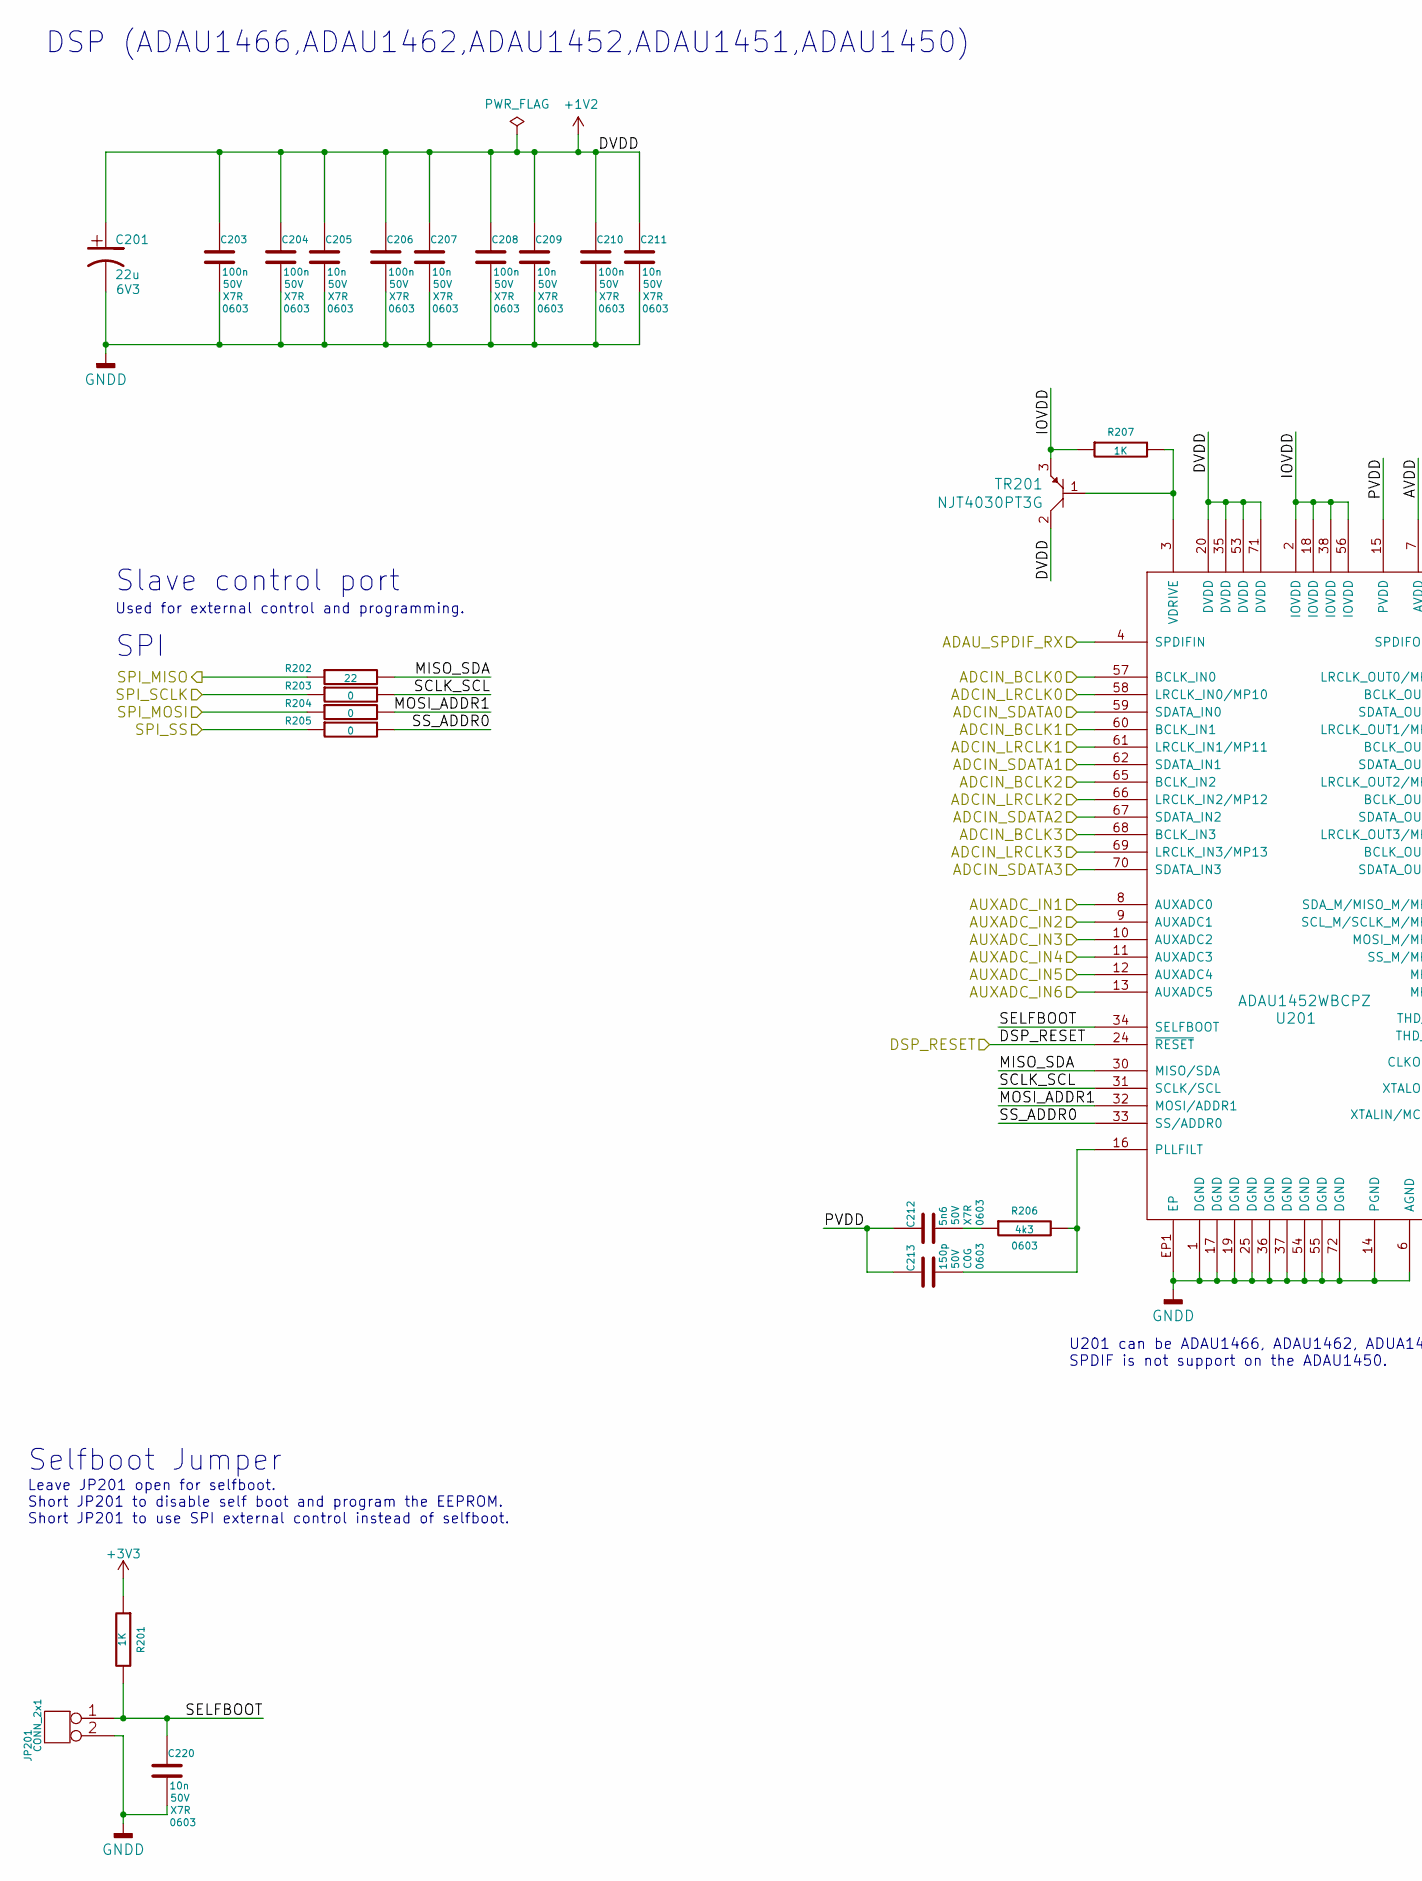
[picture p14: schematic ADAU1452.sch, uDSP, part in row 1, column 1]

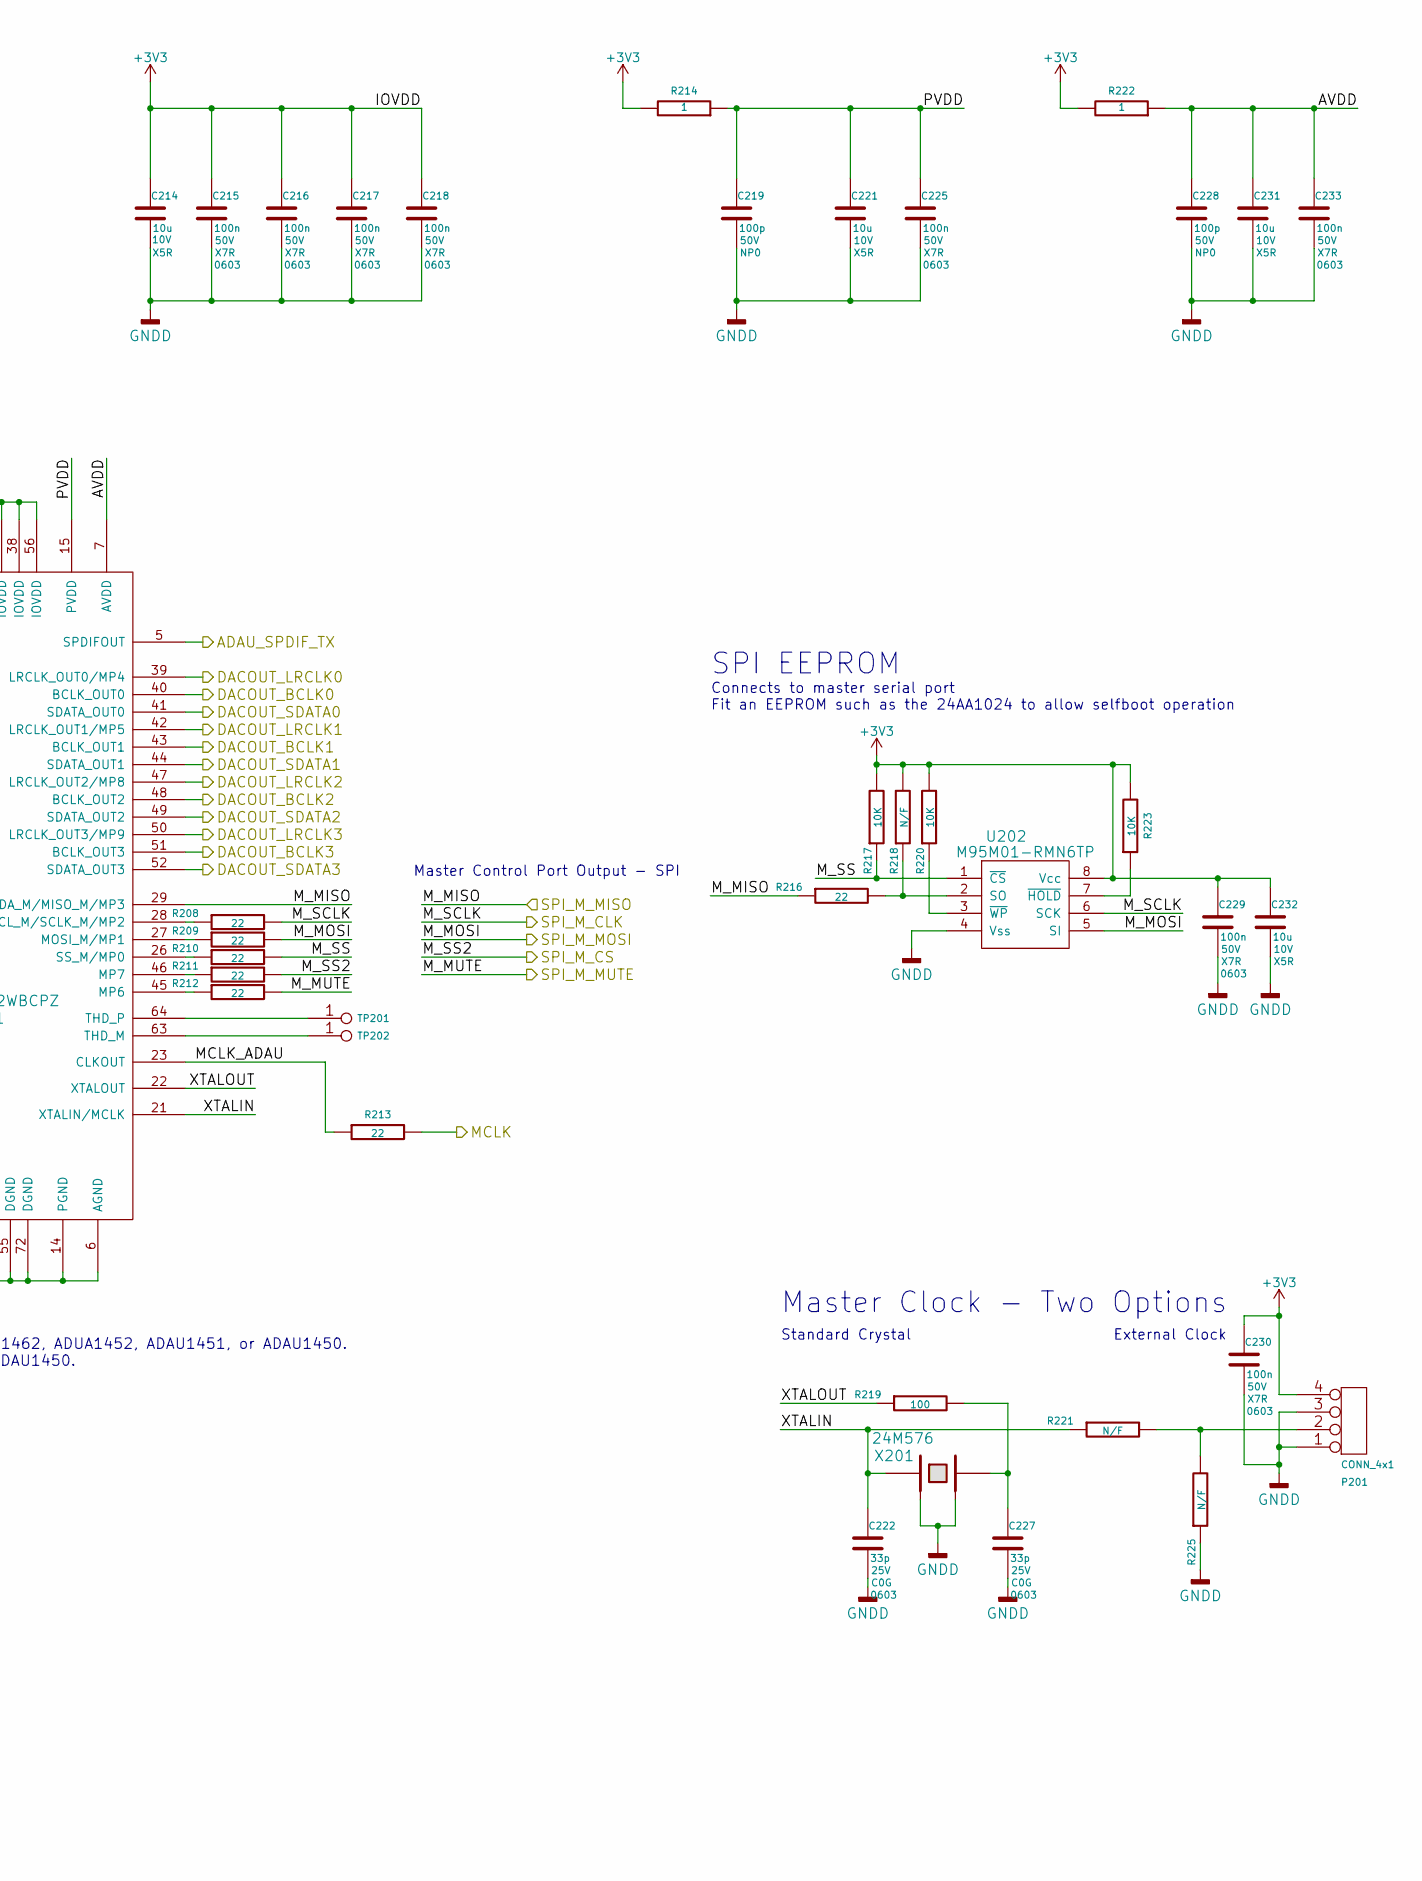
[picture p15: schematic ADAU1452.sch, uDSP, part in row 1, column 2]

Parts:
C201: 22u; CAP-SMD-SIZE-B; Voltage 6V3
C203, C204, C206, C208, C210, C215, C216, C217, C218, C225, C229, C230, C233: 100n; SMD-0603; Voltage 50V; Tolerance 10%
C205, C207, C209, C211, C220: 10n; SMD-0603; Voltage 50V; Tolerance 10%
C212: 5n6; SMD-0603; Voltage 50V; Tolerance 10%
C213: 150p; SMD-0603; Voltage 50V; Tolerance 5%
C214: 10u; SMD-0805; Voltage 10V; Tolerance 20%
C219, C228: 100p; SMD-0603; Voltage 50V; Tolerance 5%
C221, C231, C232: 10u; SMD-0603; Voltage 10V; Tolerance 10%
C222, C227: 33p; SMD-0603; Voltage 25V; Tolerance 5%
JP201: CONN_2x1; CONN_SIL_2_1MM
P201: CONN_4x1; CONN_SIL_4_1MM
R201, R207: 1K; SMD-0603; Tolerance 1%
R202, R208, R209, R210, R211, R212, R213, R216: 22; SMD-0603; Tolerance 1%
R203, R204, R205: 0; SMD-0603; Tolerance 1%
R206: 4k3; SMD-0603; Tolerance 1%
R214, R222: 1; SMD-0603; Tolerance 1%
R217, R220, R223: 10K; SMD-0603; Tolerance 1%
R218, R221, R225: N/F; SMD-0603; Tolerance 1%
R219: 100; SMD-0603; Tolerance 1%
TP201, TP202: PIN; TP-1mm
TR201: NJT4030PT3G; IC-SOT-223
U201: ADAU1452WBCPZ; IC-LFCSP72-HANDFIT
U202: M95M01-RMN6TP; IC_SOIC_8
X201: 24M576; XTAL_3.2x2.5_4PIN

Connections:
+1V2: C201.1, C203.1, C204.1, C205.1, C206.1, C207.1, C208.1, C209.1, C210.1, C211.1, TR201.2, U201.20 (DVDD), U201.35 (DVDD), U201.53 (DVDD), U201.71 (DVDD); also elsewhere on the board
/AUXADC1: U201.8 (AUXADC0); also elsewhere on the board
/AUXADC2: U201.9 (AUXADC1); also elsewhere on the board
/AUXADC3: U201.10 (AUXADC2); also elsewhere on the board
/AUXADC4: U201.11 (AUXADC3); also elsewhere on the board
/AUXADC5: U201.12 (AUXADC4); also elsewhere on the board
/AUXADC6: U201.13 (AUXADC5); also elsewhere on the board
/DSP/AVDD: C228.1, C231.1, C233.1, R222.1, U201.7 (AVDD)
/DSP/MCLK_ADAU: R213.1, U201.23 (CLKOUT)
/DSP/MISO_SDA: R202.2, U201.30 (MISO/SDA)
/DSP/MOSI_ADDR1: R204.2, U201.32 (MOSI/ADDR1)
/DSP/PVDD: C212.1, C213.1, C219.1, C221.1, C225.1, R214.1, U201.15 (PVDD)
/DSP/SCLK_SCL: R203.2, U201.31 (SCLK/SCL)
/DSP/SELFBOOT: C220.1, JP201.1, R201.2, U201.34 (SELFBOOT)
/DSP/SS_ADDR0: R205.2, U201.33 (SS/ADDR0)
/DSP/XTALIN: C222.1, R221.1, U201.21 (XTALIN/MCLK), X201.1
/DSP/XTALOUT: R219.1, U201.22 (XTALOUT)
/DSP_RESET: U201.24 (~RESET); also elsewhere on the board
/IN_BCLK0: U201.57 (BCLK_IN0); also elsewhere on the board
/IN_BCLK1: U201.60 (BCLK_IN1); also elsewhere on the board
/IN_BCLK2: U201.65 (BCLK_IN2); also elsewhere on the board
/IN_BCLK3: U201.68 (BCLK_IN3); also elsewhere on the board
/IN_LRCLK0: U201.58 (LRCLK_IN0/MP10); also elsewhere on the board
/IN_LRCLK1: U201.61 (LRCLK_IN1/MP11); also elsewhere on the board
/IN_LRCLK2: U201.66 (LRCLK_IN2/MP12); also elsewhere on the board
/IN_LRCLK3: U201.69 (LRCLK_IN3/MP13); also elsewhere on the board
/IN_SDATA0: U201.59 (SDATA_IN0); also elsewhere on the board
/IN_SDATA1: U201.62 (SDATA_IN1); also elsewhere on the board
/IN_SDATA2: U201.67 (SDATA_IN2); also elsewhere on the board
/IN_SDATA3: U201.70 (SDATA_IN3); also elsewhere on the board
/MCLK: R213.2; also elsewhere on the board
/OUT_BCLK0: U201.40 (BCLK_OUT0); also elsewhere on the board
/OUT_BCLK1: U201.43 (BCLK_OUT1); also elsewhere on the board
/OUT_BCLK2: U201.48 (BCLK_OUT2); also elsewhere on the board
/OUT_BCLK3: U201.51 (BCLK_OUT3); also elsewhere on the board
/OUT_LRCLK0: U201.39 (LRCLK_OUT0/MP4); also elsewhere on the board
/OUT_LRCLK1: U201.42 (LRCLK_OUT1/MP5); also elsewhere on the board
/OUT_LRCLK2: U201.47 (LRCLK_OUT2/MP8); also elsewhere on the board
/OUT_LRCLK3: U201.50 (LRCLK_OUT3/MP9); also elsewhere on the board
/OUT_SDATA0: U201.41 (SDATA_OUT0); also elsewhere on the board
/OUT_SDATA1: U201.44 (SDATA_OUT1); also elsewhere on the board
/OUT_SDATA2: U201.49 (SDATA_OUT2); also elsewhere on the board
/OUT_SDATA3: U201.52 (SDATA_OUT3); also elsewhere on the board
/SPDIF_RX: U201.4 (SPDIFIN); also elsewhere on the board
/SPDIF_TX: U201.5 (SPDIFOUT); also elsewhere on the board
/SPI_MISO: R202.1; also elsewhere on the board
/SPI_MOSI: R204.1; also elsewhere on the board
/SPI_M_CLK: R208.2, U202.6 (SCK); also elsewhere on the board
/SPI_M_CS2: R211.2; also elsewhere on the board
/SPI_M_MISO: R216.1, U201.29 (SDA_M/MISO_M/MP3); also elsewhere on the board
/SPI_M_MOSI: R209.2, U202.5 (SI); also elsewhere on the board
/SPI_M_MUTE: R212.2; also elsewhere on the board
/SPI_SCLK: R203.1; also elsewhere on the board
/SPI_SS: R205.1; also elsewhere on the board
GNDD: C201.2, C203.2, C204.2, C205.2, C206.2, C207.2, C208.2, C209.2, C210.2, C211.2, C214.2, C215.2, C216.2, C217.2, C218.2, C219.2, C220.2, C221.2, C222.2, C225.2, C227.2, C228.2, C229.2, C230.2, C231.2, C232.2, C233.2, JP201.2, P201.1, P201.3, R225.1, U201.1 (DGND), U201.6 (AGND), U201.14 (PGND), U201.17 (DGND), U201.19 (DGND), U201.25 (DGND), U201.36 (DGND), U201.37 (DGND), U201.54 (DGND), U201.55 (DGND), U201.72 (DGND), U201.EP1 (EP), U202.4 (Vss), X201.2, X201.4; also elsewhere on the board
unnamed: C212.2, R206.1
unnamed: C213.2, R206.2, U201.16 (PLLFILT)
unnamed: C227.1, R219.2, X201.3
unnamed: P201.2, R221.2, R225.2
unnamed: R207.2, TR201.1, U201.3 (VDRIVE)
unnamed: R208.1, U201.28 (SCL_M/SCLK_M/MP2)
unnamed: R209.1, U201.27 (MOSI_M/MP1)
unnamed: R210.1, U201.26 (SS_M/MP0)
unnamed: R211.1, U201.46 (MP7)
unnamed: R212.1, U201.45 (MP6)
unnamed: R216.2, R218.1, U202.2 (SO)
unnamed: R220.1, U202.3 (~WP)
unnamed: R223.1, U202.7 (~HOLD)
unnamed: TP201.1, U201.64 (THD_P)
unnamed: TP202.1, U201.63 (THD_M)

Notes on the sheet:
Selfboot Jumper
Leave JP201 open for selfboot. Short JP201 to disable self boot and program the EEPROM. Short JP201 to use SPI external control instead of selfboot.
SPI EEPROM
Master Clock - Two Options
Standard Crystal
Connects to master serial port Fit an EEPROM such as the 24AA1024 to allow selfboot operation
Slave control port
Used for external control and programming.
External Clock
SPI
Master Control Port Output - SPI
U201 can be ADAU1466, ADAU1462, ADUA1452, ADAU1451, or ADAU1450. SPDIF is not support on the ADAU1450.
DSP (ADAU1466,ADAU1462,ADAU1452,ADAU1451,ADAU1450)

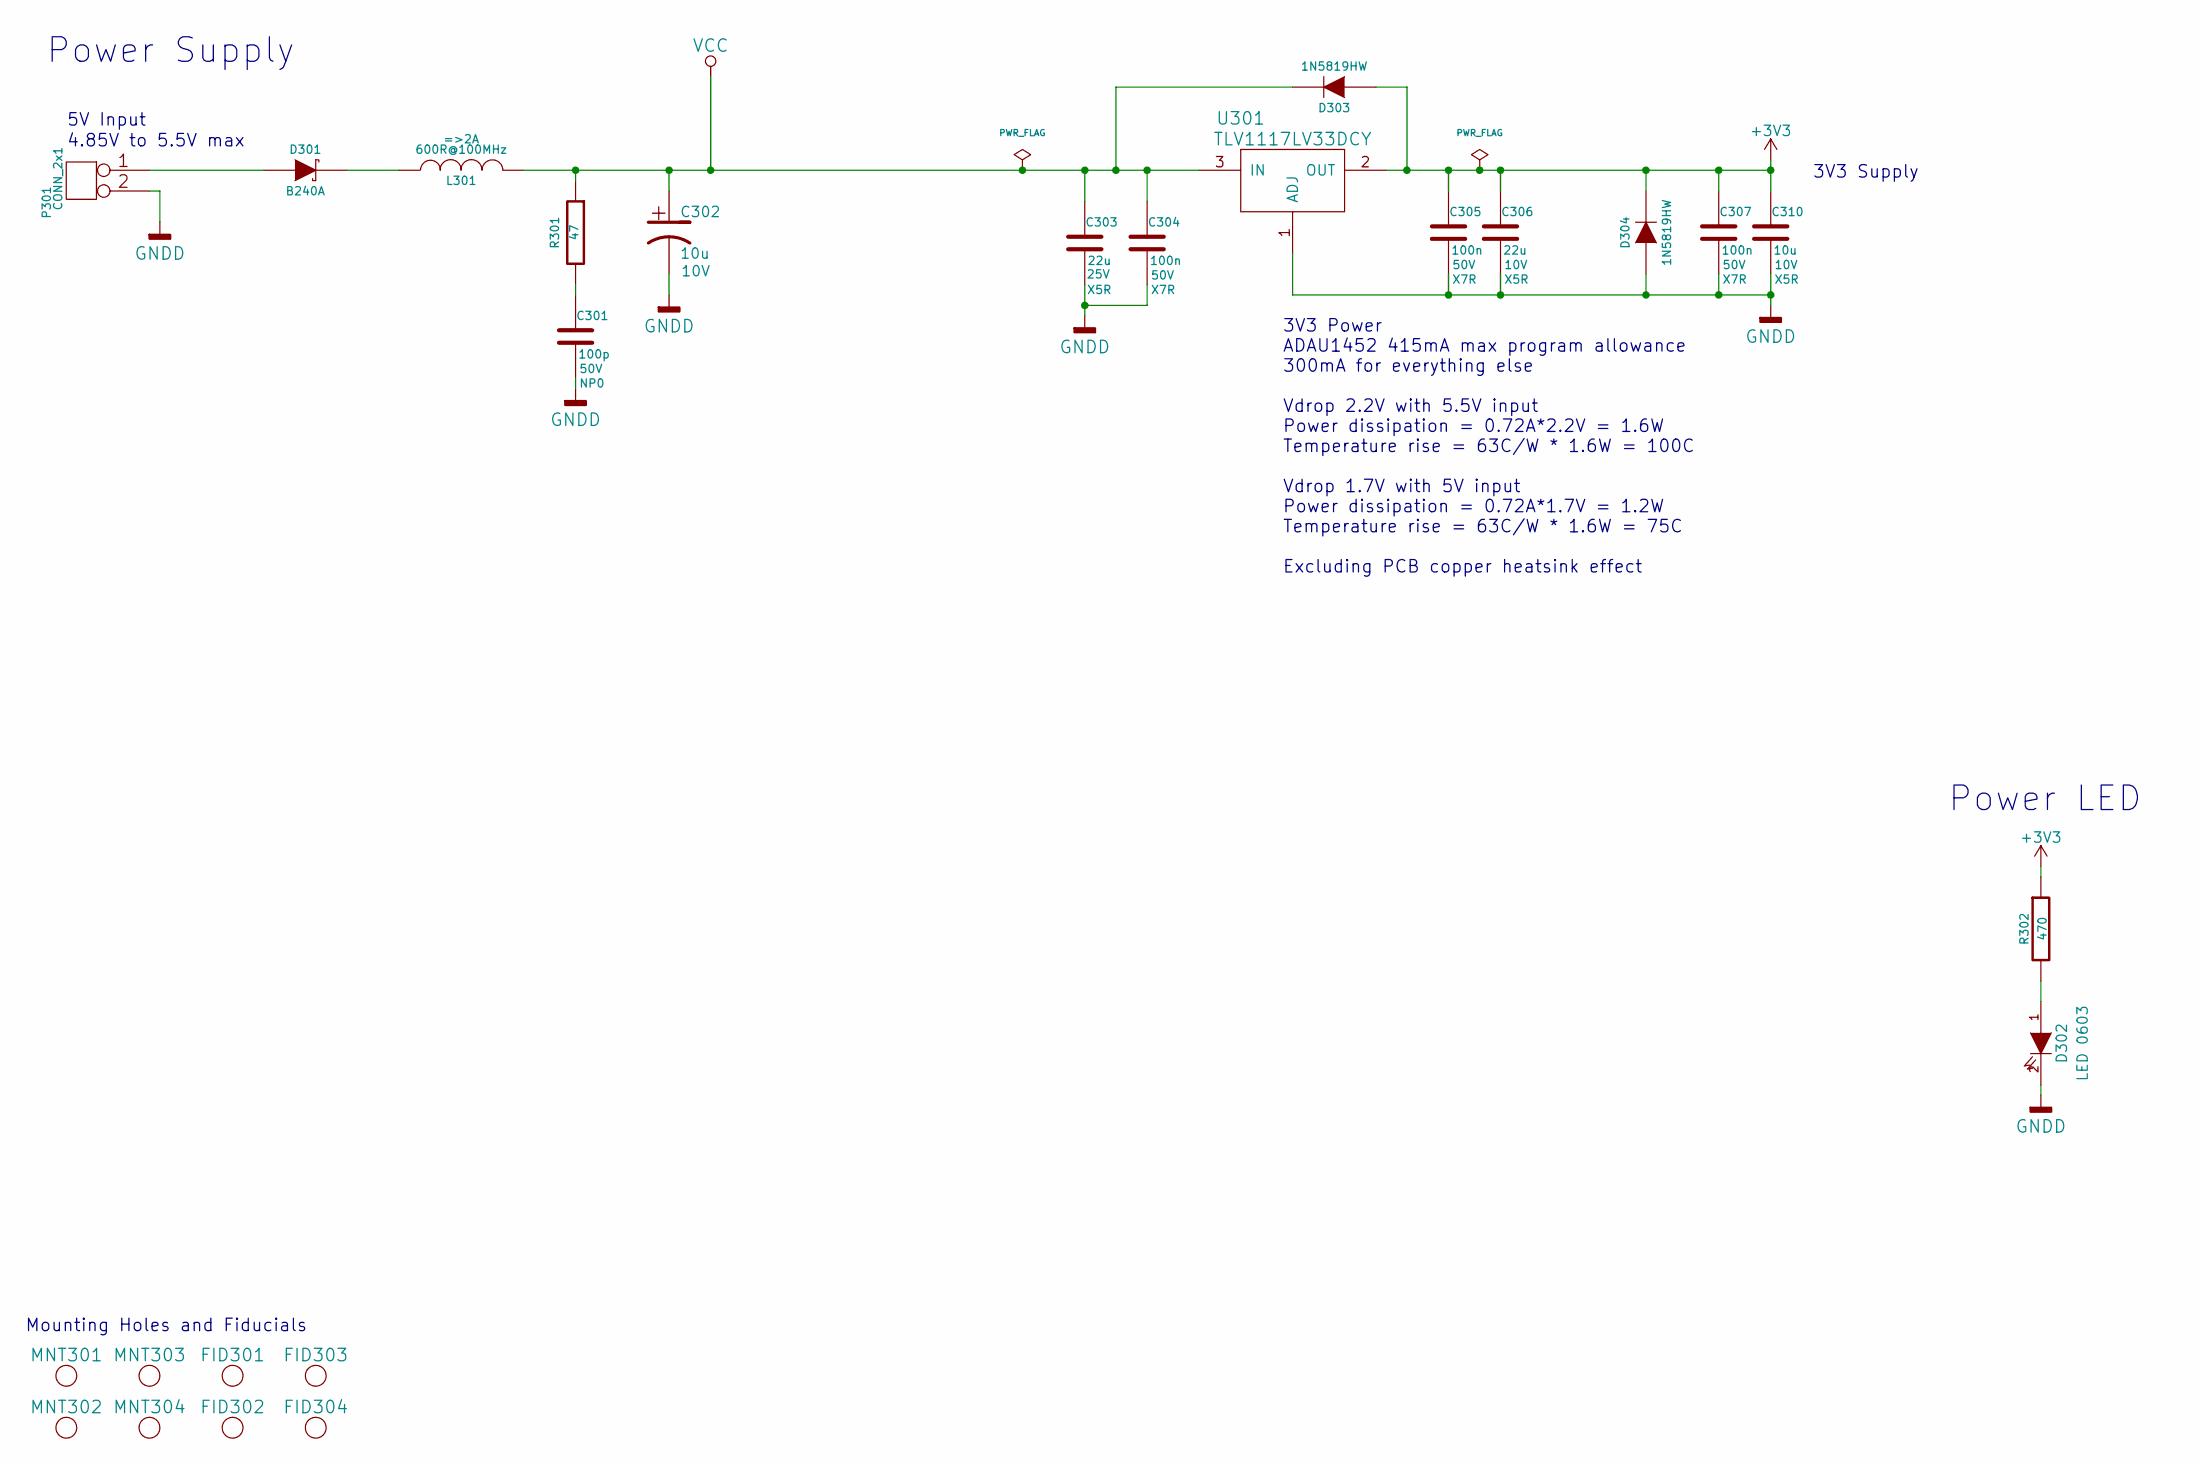
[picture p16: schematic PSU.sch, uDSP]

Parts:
C301: 100p; SMD-0603; Voltage 50V; Tolerance 5%
C302: 10u; CAP-SMD-SIZE-B; Voltage 10V
C303: 22u; SMD-0805; Voltage 25V; Tolerance 20%
C304, C305, C307: 100n; SMD-0603; Voltage 50V; Tolerance 10%
C306: 22u; SMD-0603; Voltage 10V; Tolerance 20%
C310: 10u; SMD-0603; Voltage 10V; Tolerance 20%
D301: B240A; DIODE-SMA
D302: LED 0603; SMD-0603-LED
D303, D304: 1N5819HW; DIODE-SOD-123
FID301, FID302, FID303, FID304: MNT_HOLE; FID-1MM-3MM
L301: 600R@100MHz; SMD-0805
MNT301, MNT302, MNT303, MNT304: MNT_HOLE; MNT_HOLE_3.2mm
P301: CONN_2x1; CONN-2WAY-2.54mm-3.81mm-SPACING
R301: 47; SMD-0603; Tolerance 1%
R302: 470; SMD-0603; Tolerance 1%
U301: TLV1117LV33DCY; IC-SOT-223

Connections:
GNDD: C301.2, C302.2, C303.2, C304.2, C305.2, C306.2, C307.2, C310.2, D302.2 (K), D304.1 (A), P301.2, U301.1 (ADJ); also elsewhere on the board
unnamed: C301.1, R301.2
unnamed: D301.1 (A), P301.1
unnamed: D301.2 (K), L301.1
unnamed: D302.1 (A), R302.2
VCC: C302.1, C303.1, C304.1, D303.2 (K), L301.2, R301.1, U301.3 (IN)

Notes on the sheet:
Power Supply
5V Input
3V3 Supply
Mounting Holes and Fiducials
3V3 Power ADAU1452 415mA max program allowance 300mA for everything else Vdrop 2.2V with 5.5V input Power dissipation = 0.72A*2.2V = 1.6W Temperature rise = 63C/W * 1.6W = 100C Vdrop 1.7V with 5V input Power dissipation = 0.72A*1.7V = 1.2W Temperature rise = 63C/W * 1.6W = 75C Excluding PCB copper 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
4.85V to 5.5V max
Power LED

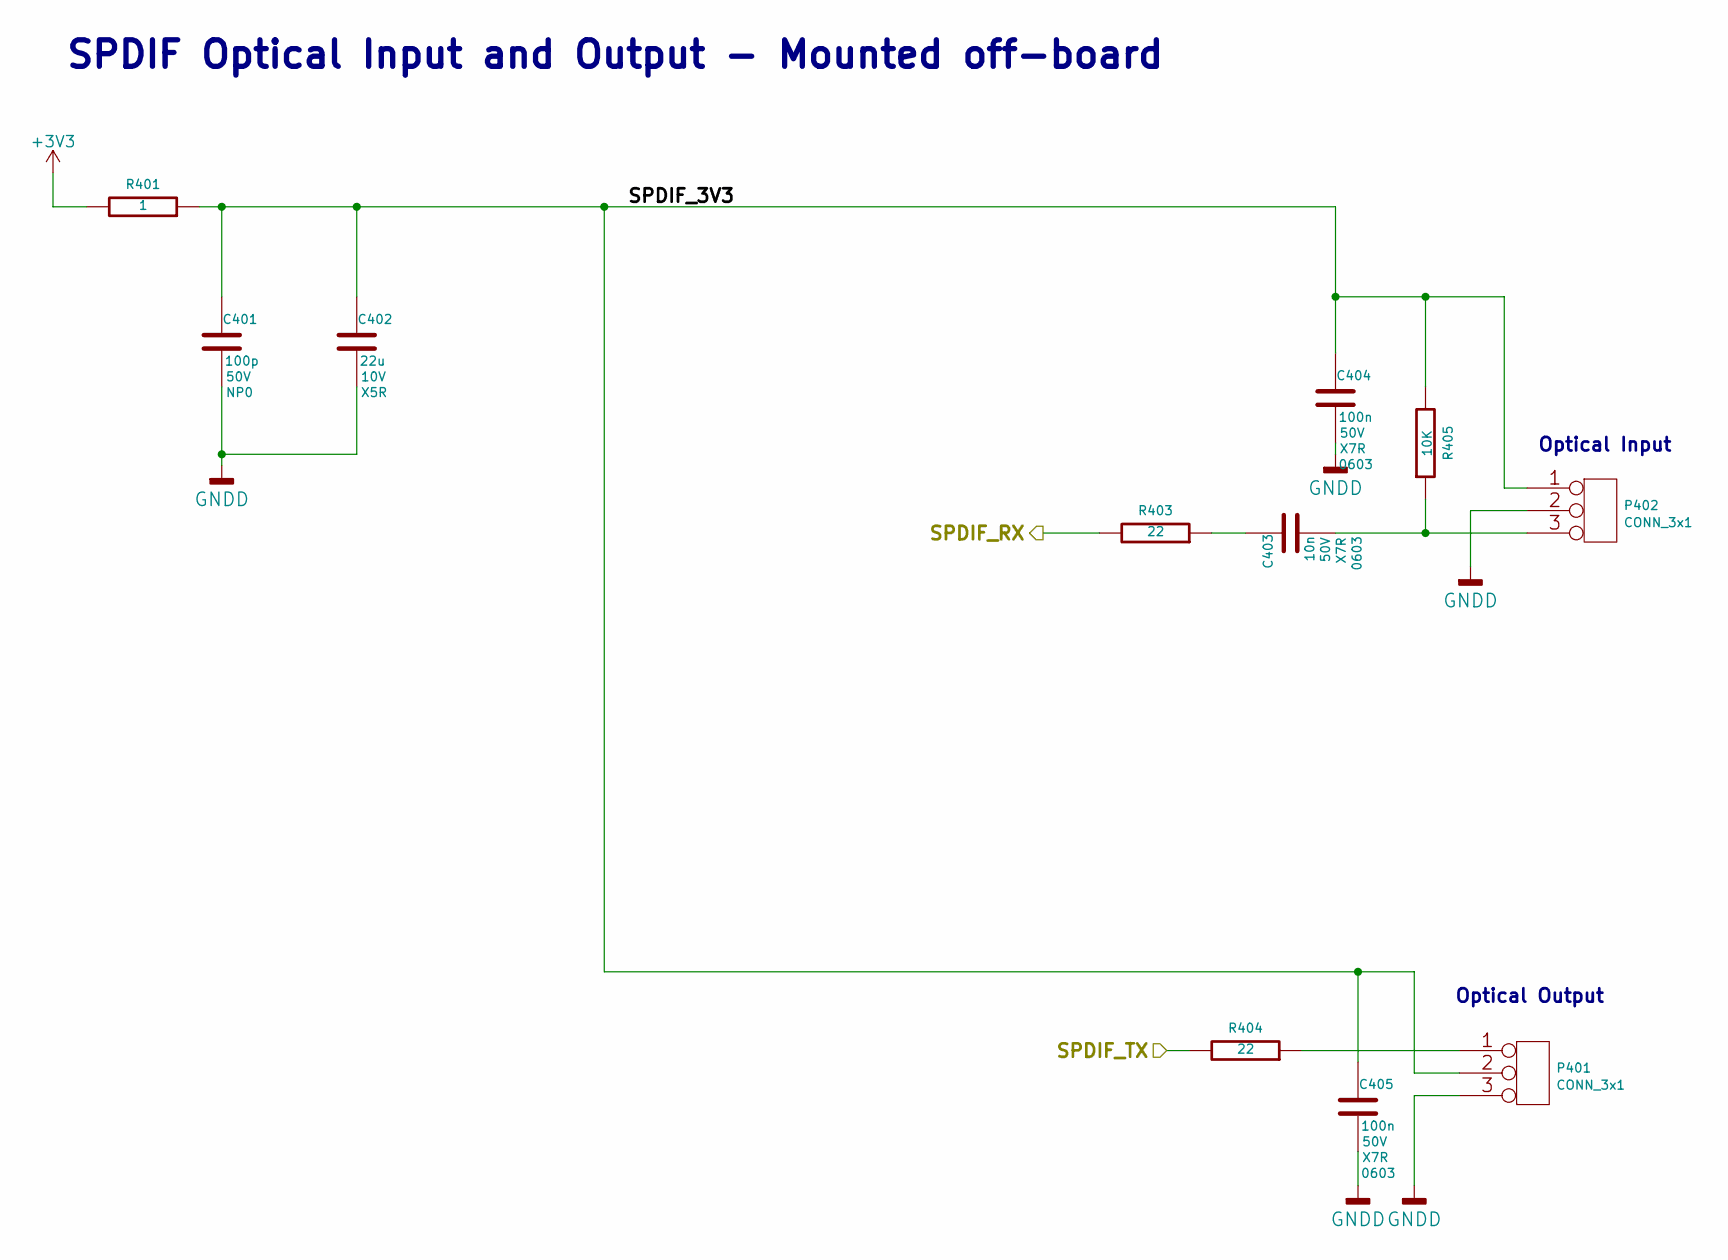
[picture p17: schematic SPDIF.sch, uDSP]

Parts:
C401: 100p; SMD-0603; Voltage 50V; Tolerance 5%
C402: 22u; SMD-0603; Voltage 10V; Tolerance 10%
C403: 10n; SMD-0603; Voltage 50V; Tolerance 10%
C404, C405: 100n; SMD-0603; Voltage 50V; Tolerance 10%
P401, P402: CONN_3x1; CONN_SIL_3_1MM
R401: 1; SMD-0603; Tolerance 1%
R403, R404: 22; SMD-0603; Tolerance 1%
R405: 10K; SMD-0603; Tolerance 1%

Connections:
/SPDIF/SPDIF_3V3: C401.1, C402.1, C404.1, C405.1, P401.2, P402.1, R401.1, R405.2
/SPDIF_RX: R403.2; also elsewhere on the board
/SPDIF_TX: R404.2; also elsewhere on the board
GNDD: C401.2, C402.2, C404.2, C405.2, P401.3, P402.2; also elsewhere on the board
unnamed: C403.1, R403.1
unnamed: C403.2, P402.3, R405.1
unnamed: P401.1, R404.1

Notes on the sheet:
SPDIF Optical Input and Output - Mounted off-board
Optical Input
Optical Output

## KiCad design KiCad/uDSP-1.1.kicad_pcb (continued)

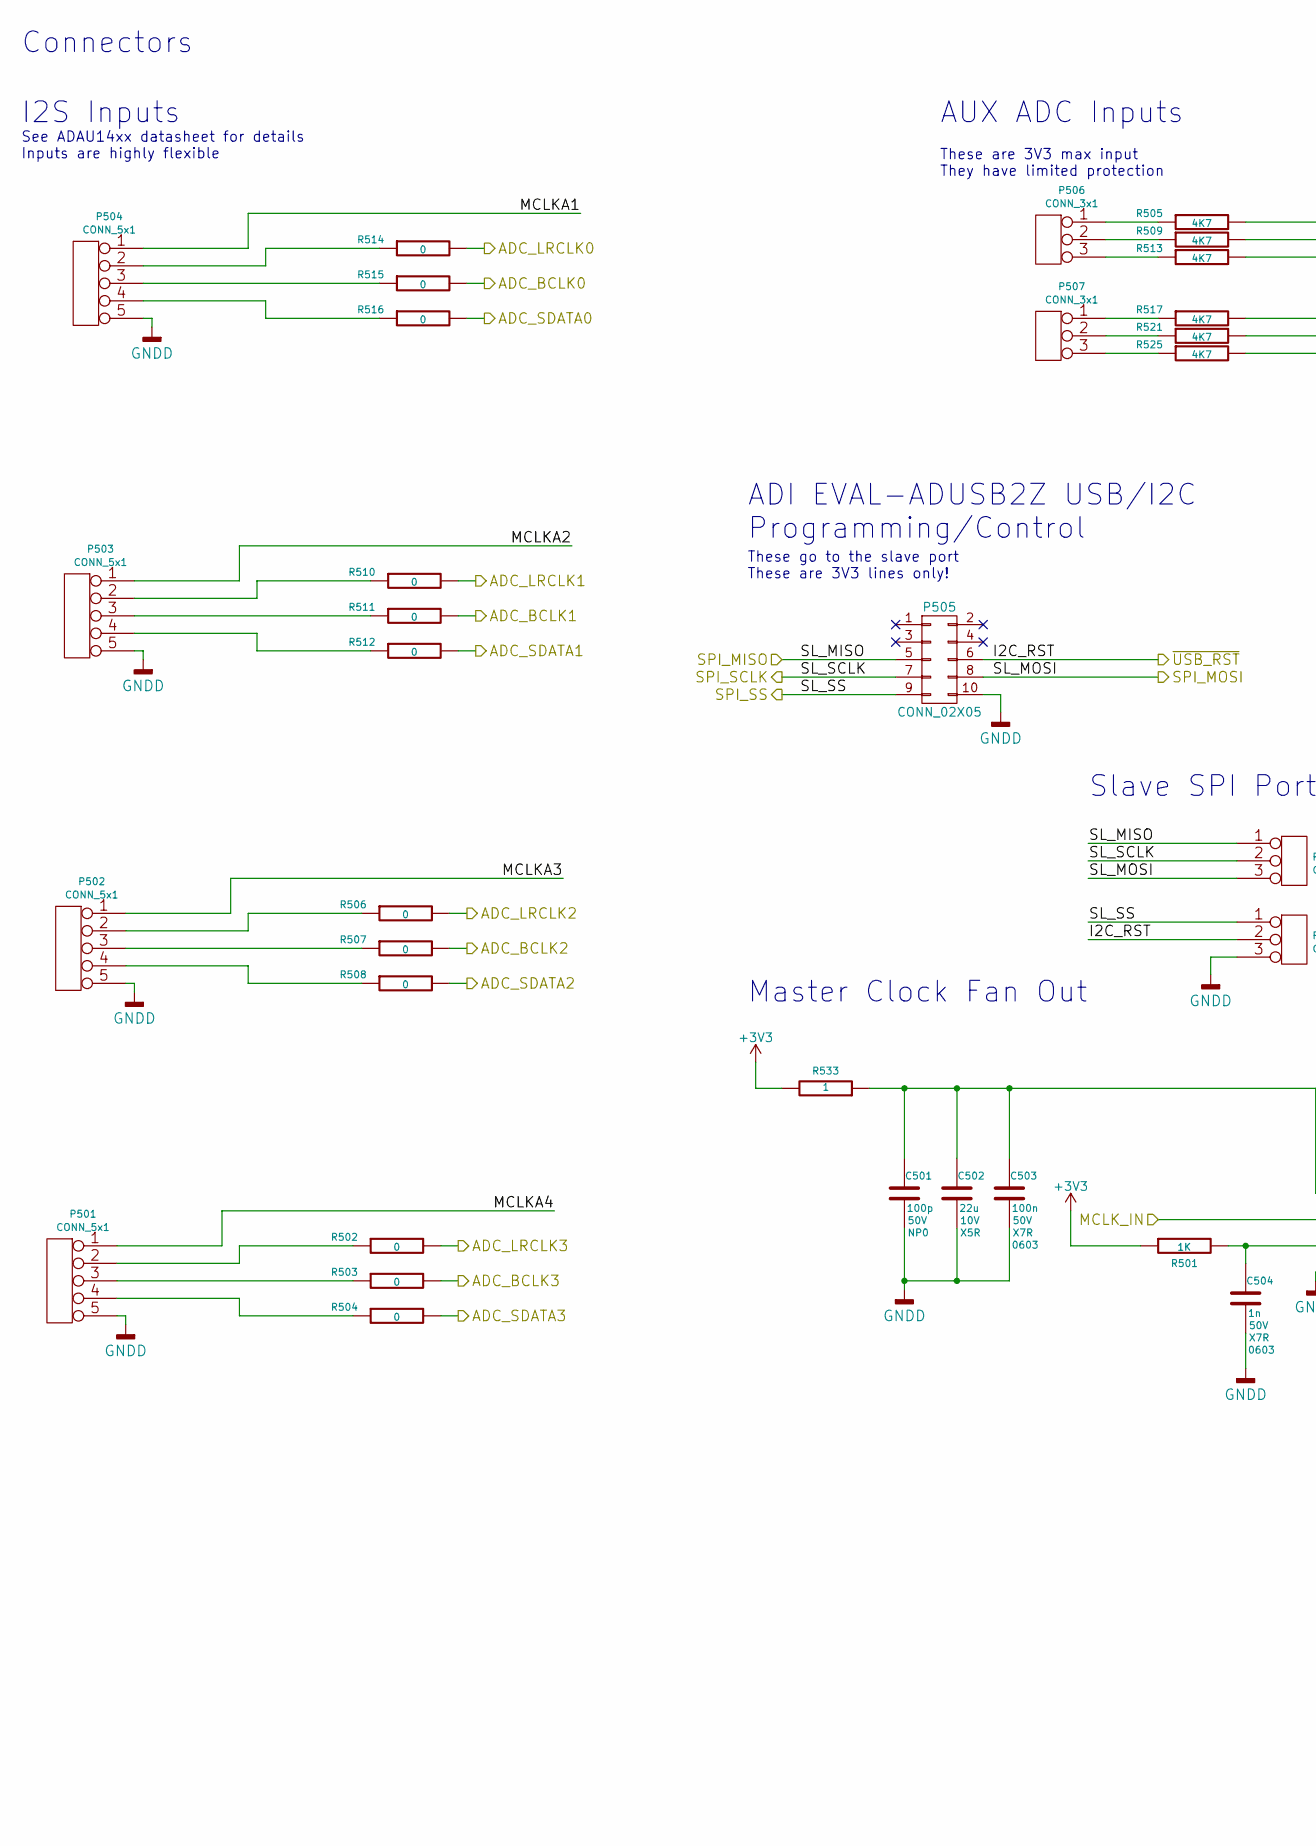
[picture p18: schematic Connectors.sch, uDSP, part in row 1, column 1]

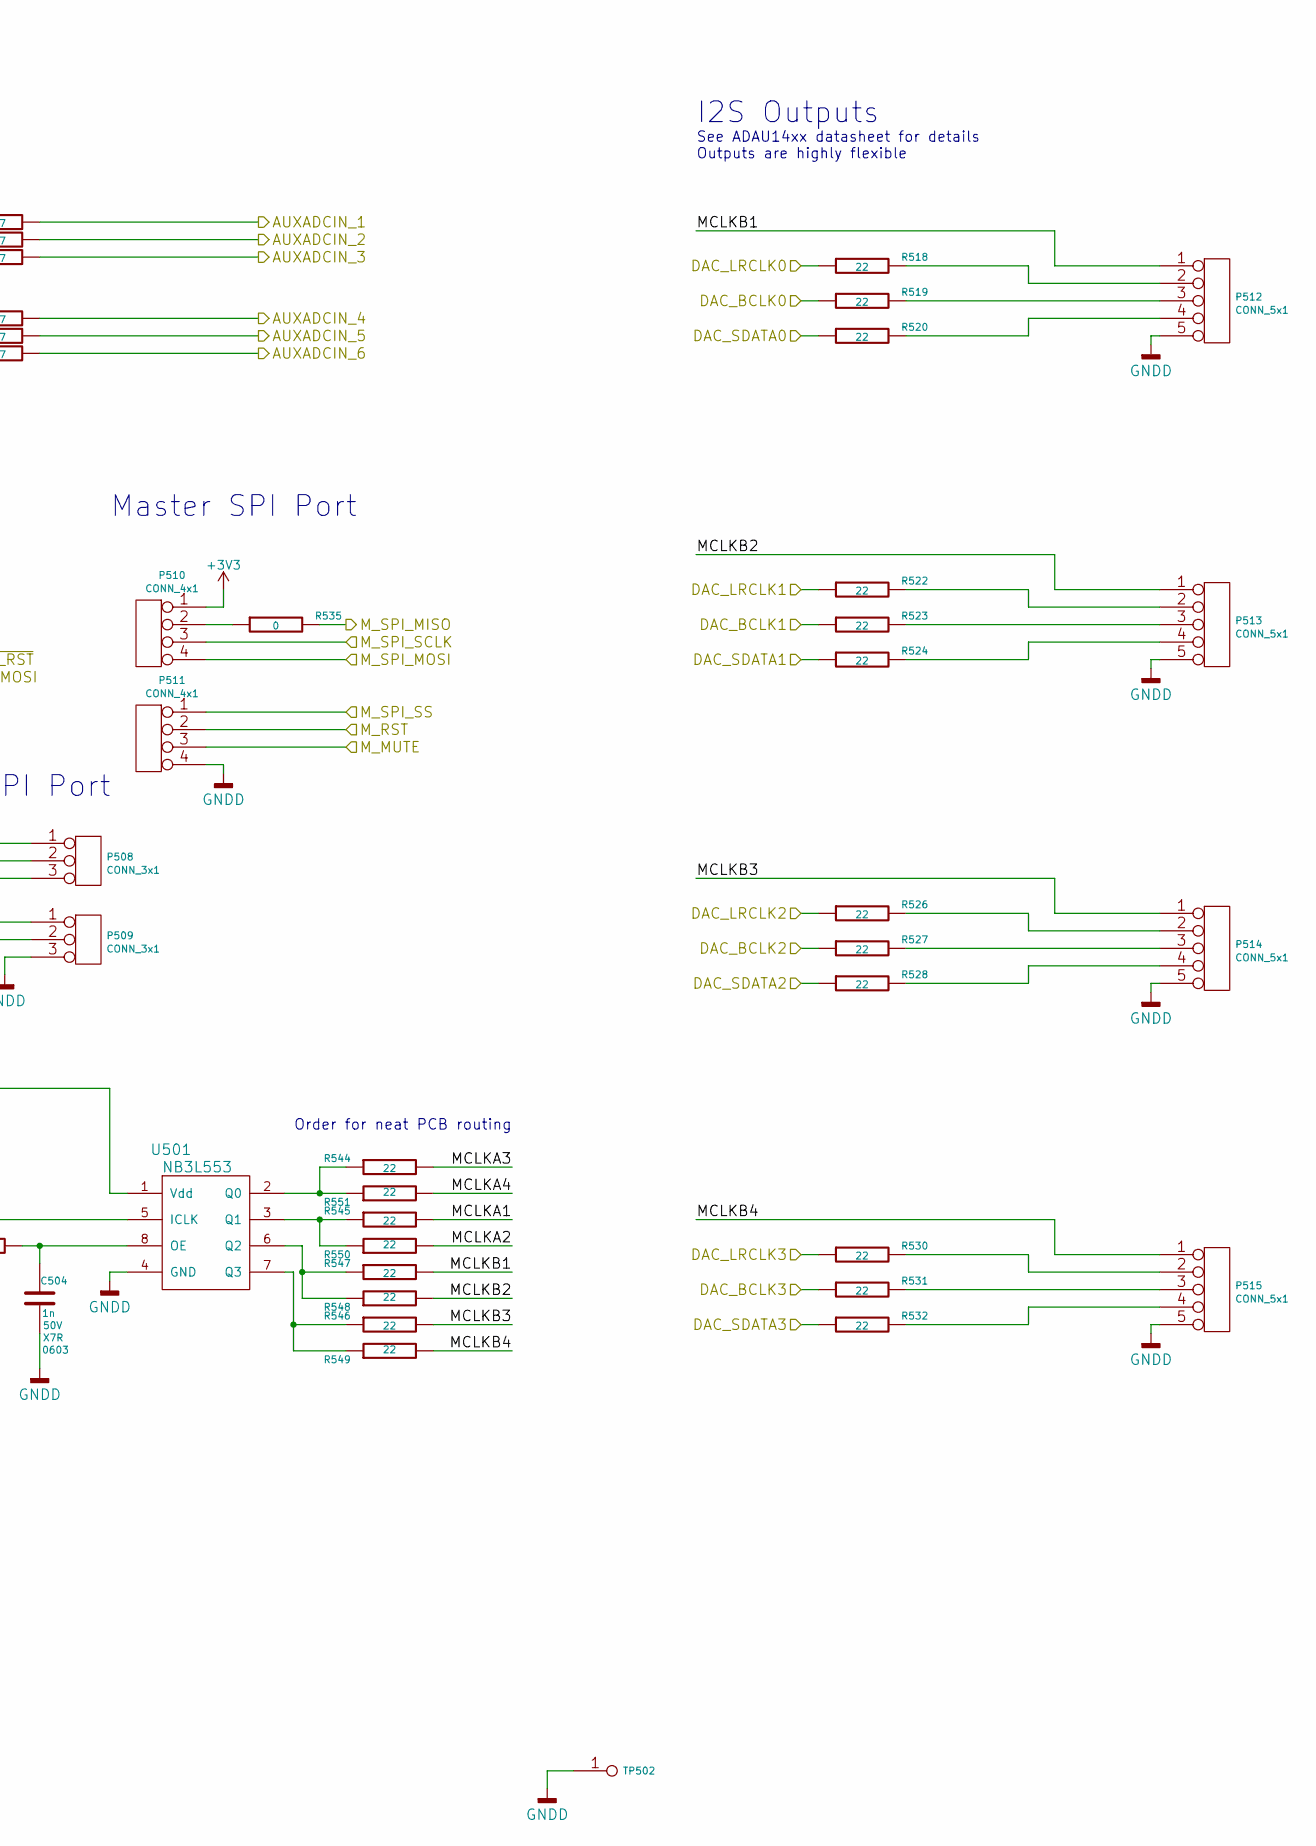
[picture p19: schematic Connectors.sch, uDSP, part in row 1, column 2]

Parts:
C501: 100p; SMD-0603; Voltage 50V; Tolerance 5%
C502: 22u; SMD-0603; Voltage 10V; Tolerance 10%
C503: 100n; SMD-0603; Voltage 50V; Tolerance 10%
C504: 1n; SMD-0603; Voltage 50V; Tolerance 10%
P501, P502, P503, P504, P512, P513, P514, P515: CONN_5x1; CONN_SIL_5_1MM
P505: CONN_02X05; CONN_DIL_2X5_BOX_1MM
P506, P507, P508, P509: CONN_3x1; CONN_SIL_3_1MM
P510, P511: CONN_4x1; CONN_SIL_4_1MM
R501: 1K; SMD-0603; Tolerance 1%
R502, R503, R504, R506, R507, R508, R510, R511, R512, R514, R515, R516, R535: 0; SMD-0603; Tolerance 1%
R505, R509, R513, R517, R521, R525: 4K7; SMD-0603; Tolerance 1%
R518, R519, R520, R522, R523, R524, R526, R527, R528, R530, R531, R532, R544, R545, R546, R547, R548, R549, R550, R551: 22; SMD-0603; Tolerance 1%
R533: 1; SMD-0603; Tolerance 1%
TP502: PIN; TP-TH-1mm
U501: NB3L553; IC_SOIC_8

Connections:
/AUXADC1: R505.2; also elsewhere on the board
/AUXADC2: R509.2; also elsewhere on the board
/AUXADC3: R513.2; also elsewhere on the board
/AUXADC4: R517.2; also elsewhere on the board
/AUXADC5: R521.2; also elsewhere on the board
/AUXADC6: R525.2; also elsewhere on the board
/Connectors/MCLKA1: P504.1, R545.2
/Connectors/MCLKA2: P503.1, R550.2
/Connectors/MCLKA3: P502.1, R544.2
/Connectors/MCLKA4: P501.1, R551.2
/Connectors/MCLKB1: P512.1, R547.2
/Connectors/MCLKB2: P513.1, R548.2
/Connectors/MCLKB3: P514.1, R546.2
/Connectors/MCLKB4: P515.1, R549.2
/GLB_RESET: P511.2; also elsewhere on the board
/IN_BCLK0: R515.2; also elsewhere on the board
/IN_BCLK1: R511.2; also elsewhere on the board
/IN_BCLK2: R507.2; also elsewhere on the board
/IN_BCLK3: R503.2; also elsewhere on the board
/IN_LRCLK0: R514.2; also elsewhere on the board
/IN_LRCLK1: R510.2; also elsewhere on the board
/IN_LRCLK2: R506.2; also elsewhere on the board
/IN_LRCLK3: R502.2; also elsewhere on the board
/IN_SDATA0: R516.2; also elsewhere on the board
/IN_SDATA1: R512.2; also elsewhere on the board
/IN_SDATA2: R508.2; also elsewhere on the board
/IN_SDATA3: R504.2; also elsewhere on the board
/MAN_RESET: P505.6, P509.2; also elsewhere on the board
/MCLK: U501.5 (ICLK); also elsewhere on the board
/OUT_BCLK0: R519.1; also elsewhere on the board
/OUT_BCLK1: R523.1; also elsewhere on the board
/OUT_BCLK2: R527.1; also elsewhere on the board
/OUT_BCLK3: R531.1; also elsewhere on the board
/OUT_LRCLK0: R518.1; also elsewhere on the board
/OUT_LRCLK1: R522.1; also elsewhere on the board
/OUT_LRCLK2: R526.1; also elsewhere on the board
/OUT_LRCLK3: R530.1; also elsewhere on the board
/OUT_SDATA0: R520.1; also elsewhere on the board
/OUT_SDATA1: R524.1; also elsewhere on the board
/OUT_SDATA2: R528.1; also elsewhere on the board
/OUT_SDATA3: R532.1; also elsewhere on the board
/SPI_MISO: P505.5, P508.1; also elsewhere on the board
/SPI_MOSI: P505.8, P508.3; also elsewhere on the board
/SPI_M_CLK: P510.3; also elsewhere on the board
/SPI_M_CS2: P511.1; also elsewhere on the board
/SPI_M_MISO: R535.2; also elsewhere on the board
/SPI_M_MOSI: P510.4; also elsewhere on the board
/SPI_M_MUTE: P511.3; also elsewhere on the board
/SPI_SCLK: P505.7, P508.2; also elsewhere on the board
/SPI_SS: P505.9, P509.1; also elsewhere on the board
GNDD: C501.2, C502.2, C503.2, C504.2, P501.5, P502.5, P503.5, P504.5, P505.10, P509.3, P511.4, P512.5, P513.5, P514.5, P515.5, TP502.1, U501.4 (GND); also elsewhere on the board
unnamed: C501.1, C502.1, C503.1, R533.1, U501.1 (Vdd)
unnamed: C504.1, R501.2, U501.8 (OE)
unnamed: P501.2, R502.1
unnamed: P501.3, R503.1
unnamed: P501.4, R504.1
unnamed: P502.2, R506.1
unnamed: P502.3, R507.1
unnamed: P502.4, R508.1
unnamed: P503.2, R510.1
unnamed: P503.3, R511.1
unnamed: P503.4, R512.1
unnamed: P504.2, R514.1
unnamed: P504.3, R515.1
unnamed: P504.4, R516.1
unnamed: P506.1, R505.1
unnamed: P506.2, R509.1
unnamed: P506.3, R513.1
unnamed: P507.1, R517.1
unnamed: P507.2, R521.1
unnamed: P507.3, R525.1
unnamed: P510.2, R535.1
unnamed: P512.2, R518.2
unnamed: P512.3, R519.2
unnamed: P512.4, R520.2
unnamed: P513.2, R522.2
unnamed: P513.3, R523.2
unnamed: P513.4, R524.2
unnamed: P514.2, R526.2
unnamed: P514.3, R527.2
unnamed: P514.4, R528.2
unnamed: P515.2, R530.2
unnamed: P515.3, R531.2
unnamed: P515.4, R532.2
unnamed: R544.1, R551.1, U501.2 (Q0)
unnamed: R545.1, R550.1, U501.3 (Q1)
unnamed: R546.1, R549.1, U501.7 (Q3)
unnamed: R547.1, R548.1, U501.6 (Q2)

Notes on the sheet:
ADI EVAL-ADUSB2Z USB/I2C Programming/Control
AUX ADC Inputs
These go to the slave port These are 3V3 lines only!
I2S Inputs
See ADAU14xx datasheet for details Inputs are highly flexible
I2S Outputs
These are 3V3 max input They have limited protection
See ADAU14xx datasheet for details Outputs are highly flexible
Order for neat PCB routing
Master Clock Fan Out
Master SPI Port
Slave SPI Port
Connectors

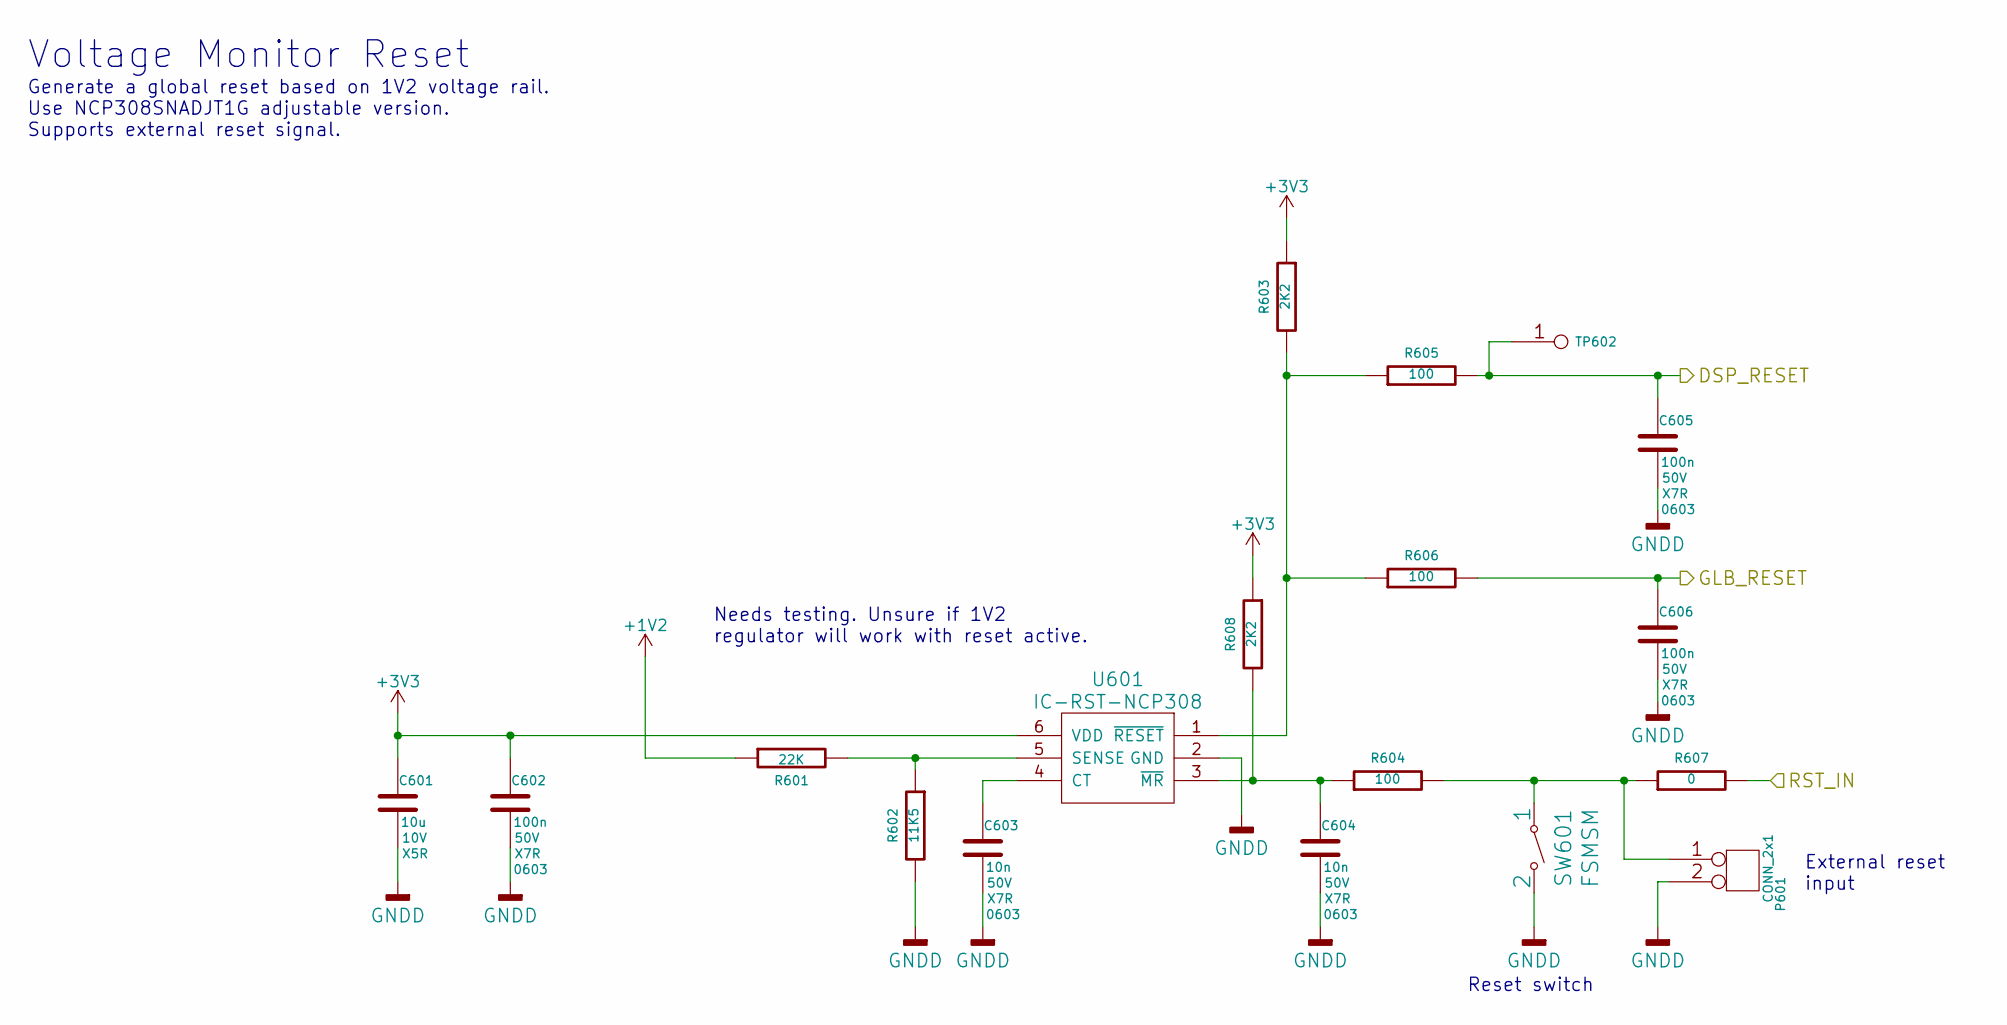
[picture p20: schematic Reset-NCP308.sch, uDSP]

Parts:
C601: 10u; SMD-0603; Voltage 10V; Tolerance 20%
C602, C605, C606: 100n; SMD-0603; Voltage 50V; Tolerance 10%
C603, C604: 10n; SMD-0603; Voltage 50V; Tolerance 10%
P601: CONN_2x1; CONN_SIL_2_1MM
R601: 22K; SMD-0603; Tolerance 1%
R602: 11K5; SMD-0603; Tolerance 1%
R603, R608: 2K2; SMD-0603; Tolerance 1%
R604, R605, R606: 100; SMD-0603; Tolerance 1%
R607: 0; SMD-0603; Tolerance 1%
SW601: FSMSM; SW_TACT_SMD_FSMSM
TP602: PIN; TP-1mm
U601: IC-RST-NCP308; IC-SOT23-6

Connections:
+1V2: R601.1; also elsewhere on the board
/DSP_RESET: C605.1, R605.2, TP602.1; also elsewhere on the board
/GLB_RESET: C606.1, R606.2; also elsewhere on the board
/MAN_RESET: R607.2; also elsewhere on the board
GNDD: C601.2, C602.2, C603.2, C604.2, C605.2, C606.2, P601.2, R602.2, SW601.2, U601.2 (GND); also elsewhere on the board
unnamed: C603.1, U601.4 (CT)
unnamed: C604.1, R604.1, R608.2, U601.3 (~MR)
unnamed: P601.1, R604.2, R607.1, SW601.1
unnamed 126: R601.2, R602.1, U601.5 (SENSE); also elsewhere on the board
unnamed: R603.2, R605.1, R606.1, U601.1 (~RESET)

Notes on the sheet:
Generate a global reset based on 1V2 voltage rail. Use NCP308SNADJT1G adjustable version. Supports external reset signal.
Voltage Monitor Reset
External reset input
Needs testing. Unsure if 1V2 regulator will work with reset active.
Reset switch

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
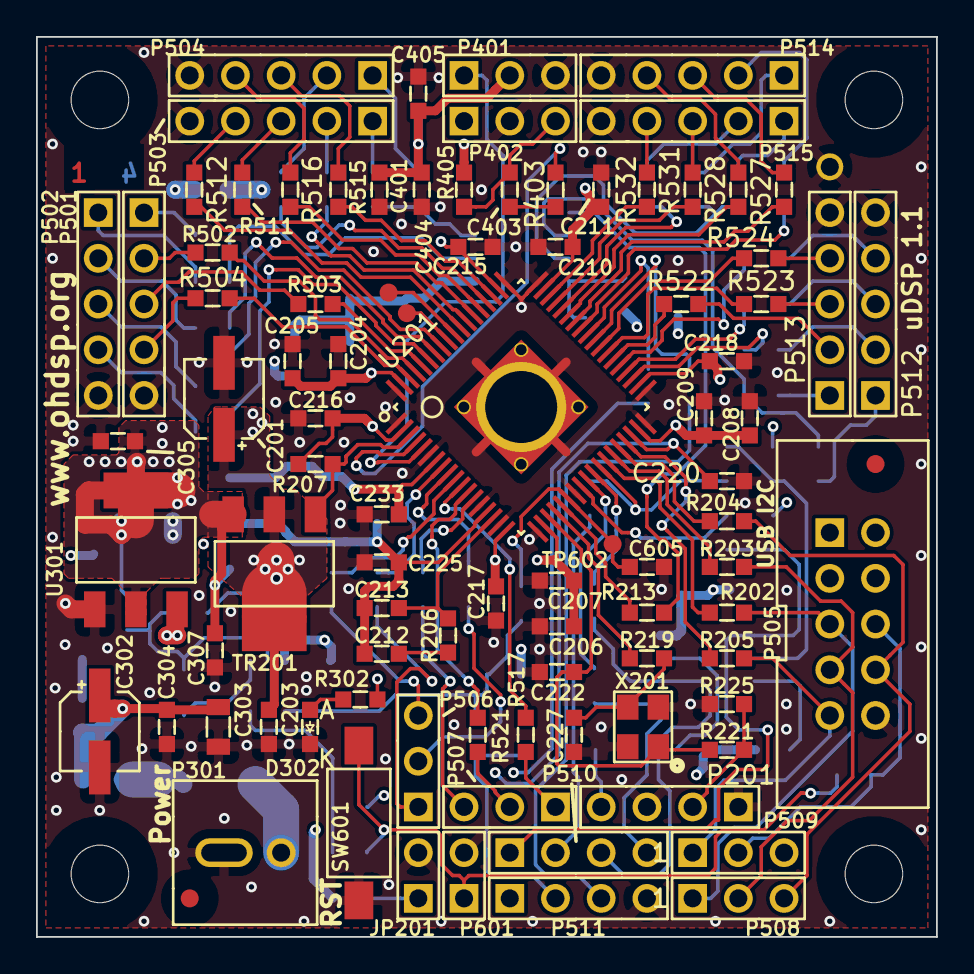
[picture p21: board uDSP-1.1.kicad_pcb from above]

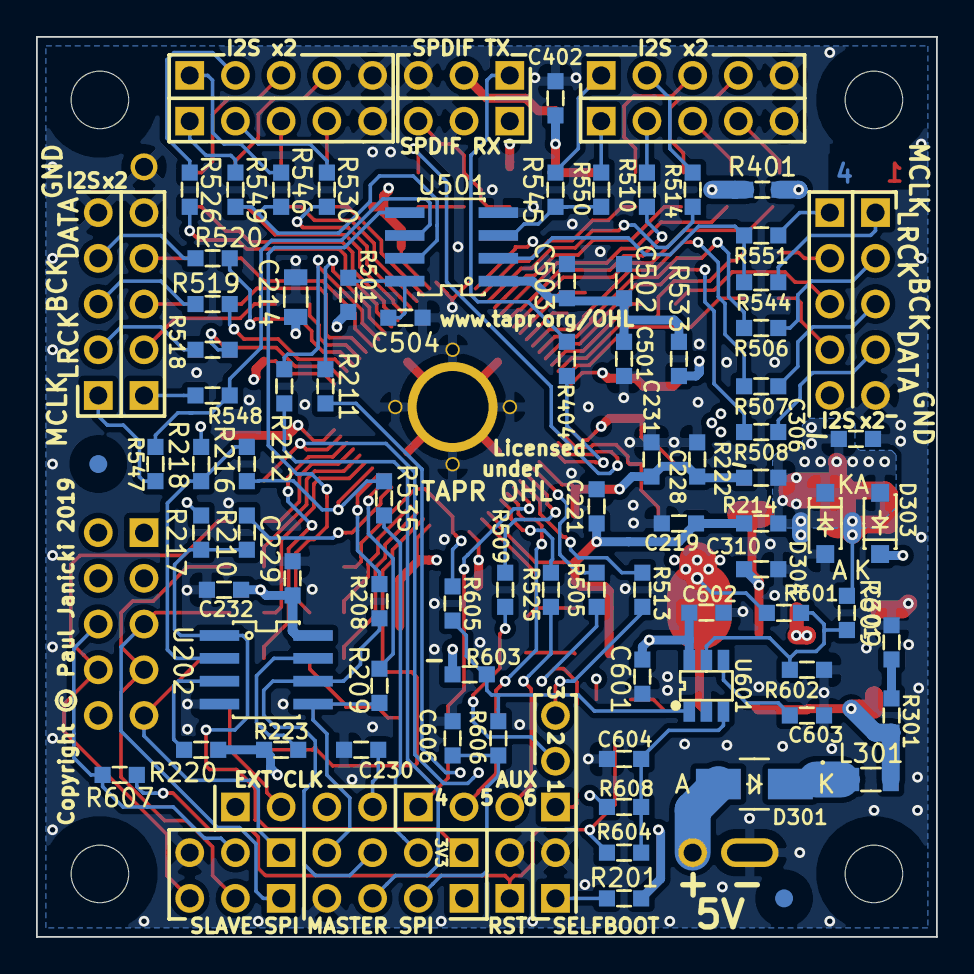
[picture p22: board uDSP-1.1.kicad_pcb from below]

Board: 4 copper layers, 50.0 x 50.0 mm, 177 parts (80 on the bottom side), 133 nets.

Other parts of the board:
R609: N/F; SMD-0603

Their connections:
unnamed 126: R609.2; also elsewhere on the board

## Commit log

2019-03-11 uDSP-1.0
    Revision 1.0 release
    [ADAU1452.sch, Connectors.sch, PSU.sch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]
2019-04-02 uDSP 1.1
    uDSP 1.1
    Add CS1 and CS2 to SPI headers - removed 3V3 power
    Add 3V3 monitor option to reset circuit
    [ADAU1452 PSU-2018-09-05-13-08-19.sch, ADAU1452-2018-09-05-13-08-19.sch, Connectors-2018-09-05-13-08-19.sch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]

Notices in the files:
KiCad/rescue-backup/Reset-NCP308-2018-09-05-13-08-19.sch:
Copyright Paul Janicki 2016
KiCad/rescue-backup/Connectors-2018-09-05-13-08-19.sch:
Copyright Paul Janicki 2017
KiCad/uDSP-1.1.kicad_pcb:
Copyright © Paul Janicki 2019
